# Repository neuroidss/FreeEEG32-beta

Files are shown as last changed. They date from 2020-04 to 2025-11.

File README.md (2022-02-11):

# FreeEEG32-beta

### FreeEEG32 Beta, launching soon on [Crowd Supply](https://www.crowdsupply.com/neuroidss/freeeeg32)!

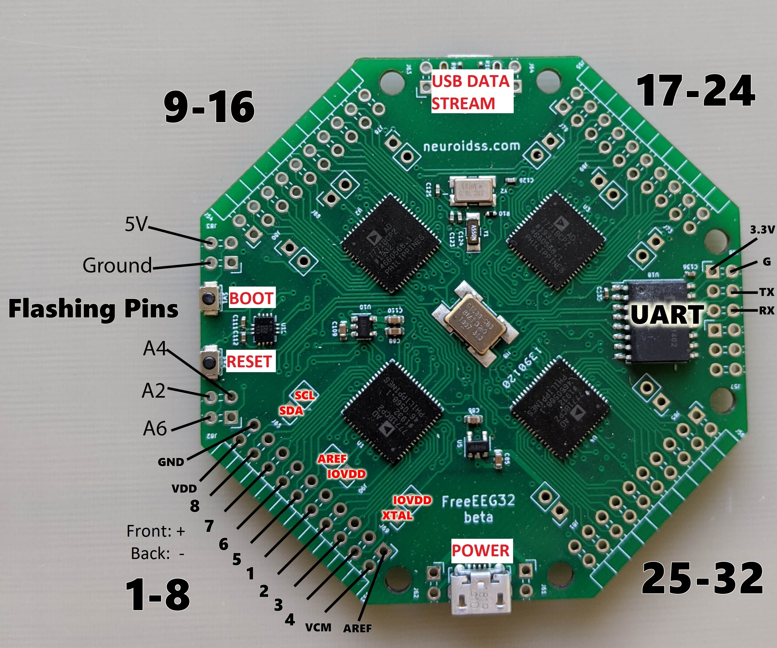
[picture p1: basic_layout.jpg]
basic_layout


### Setup

Docker container setup (Linux). Extract the following and run:
- Compilation: `./gcc-arm-none-eabi_run.sh`
- Flashing: `sudo ./openocd_flash.sh`

[Flashing via AC6 with STM32 Blue Pill](https://github.com/neuroidss/FreeEEG32-beta/blob/master/SetupGuides/FreeEEG32_Flashing_via_AC6_w_STM32F103_BluePill.md)

The AC6 stuff is deprecated but the blue pill is still needed.

[OpenVIBE Setup](https://github.com/neuroidss/FreeEEG32-beta/blob/master/SetupGuides/FreeEEG32_OpenVibe_Docker_Readme.md)

### Production files
Gerber:   https://github.com/neuroidss/FreeEEG32-beta/blob/master/AssemblyFiles/KiCAD/out/gerber.zip

Assembly: https://github.com/neuroidss/FreeEEG32-beta/blob/master/AssemblyFiles/KiCAD/out/assembly.zip

BOM:      https://github.com/neuroidss/FreeEEG32-beta/blob/master/AssemblyFiles/bom/components%20FreeEEG32%20beta.csv

PCB fabrication constraints:
* Dims: 70mm x 70mm
* Layers: 4
* Thickness: 1.6mm (can vary, thicker = sturdier)
* Surface finish: HASL Lead free or ENIG (more expensive)
* Material: FR4

Assembly constraints:
* Unique parts: 33 (27 without pin headers)
* SMT Pads:  169
* Thruhole: 23 (pin headers only)
* Assembly sides: both

This project is being launched with the help of [HEG Alpha](hegalpha.com) to make science more accessible.
Custom 2 channel and 19 channel headsets are available by Bernard Markus.

### More

Neuroidss home: https://neuroidss.com

[Alpha 1.5 repo with more content and tests](https://github.com/neuroidss/FreeEEG32-alpha1.5)

[BrainFlow support](https://brainflow.readthedocs.io/en/stable/)

[Webapp (WIP)](https://github.com/moothyknight/eegpwa)

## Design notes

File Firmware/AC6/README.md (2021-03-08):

Use these files in AC6 or with OpenOCD to update the hardware.

Recent Updates
- Windows compatibility
- 80Mhz downclock for power saving / heat

Notes:
Output is functionally only 256Hz for some reason and printing duplicates at 512Hz.

Search "dec" in Src/main.c to tweak decimation rate settings which will change it, we are working on finding the best fix.

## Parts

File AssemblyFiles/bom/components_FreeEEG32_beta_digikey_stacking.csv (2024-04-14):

Designator | Manufacturer Part Number or Seeed SKU | Qty | Link | Description | alt
U1,U2,U4,U3 | AD7771BCPZ | 4 | https://www.digikey.it/en/products/detail/analog-devices-inc/AD7771BCPZ/7649198 | IC ADC 24BIT SIGMA-DELTA 64LFCSP
U7 | ADR4525BRZ | 1 | https://www.digikey.it/en/products/detail/analog-devices-inc/ADR4525BRZ/3196871 | IC VREF SERIES 2.5V 8SOIC
U18 | ADUM1402BRWZ | 1 | https://www.digikey.it/en/products/detail/analog-devices-inc/ADUM1402BRWZ/655701 | digital isolator 10Mbps 2.7÷5.5VDC SMD SO16-W | ADUM142E1BRWZ
U17 | ADUM3160BRWZ | 1 | https://www.digikey.it/en/products/detail/analog-devices-inc/ADUM3160BRWZ/2361054 | Digital Isolator CMOS 2-CH 12Mbps 16-Pin SOIC W Tube
U8 | CB3LV-3I-8M1920 | 1 | https://www.digikey.it/en/products/detail/cts-frequency-controls/CB3LV-3I-8M192000/663652 | XTAL OSC XO 8.1920MHZ HCMOS TTL
Y1 | FC-135 32.7680KA-A5 | 1 | https://www.digikey.it/en/products/detail/epson/FC-135-32-7680KA-A5/5259895 | CRYSTAL 32.7680 KHZ 12.5PF SMD
J53,J56,J55,J54 | 68021-220HLF | 4 | https://www.digikey.it/en/products/detail/amphenol-cs-fci/68021-220HLF/1878576 | CONN HEADER R/A 20POS 2.54MM
C122 | C0603C475K9PACTU | 1 | https://www.digikey.it/en/products/detail/kemet/C0603C475K9PAC7867/754744 | CAP CER 4.7UF 6.3V 10% X5R 0603
J37,J51 | 105017-1001 | 2 | https://www.digikey.it/en/products/detail/molex/1050171001/5293188 | CONN RCPT USB2.0 MICRO B SMD R/A
U13 | 47352-1001 | 1 | https://www.digikey.it/en/products/detail/molex/0473521001/2404949 | CONN MICRO SD CARD PUSH-PUSH R/A
C125,C123,C126,C124 | GRM1555C1H200JA01D | 4 | https://www.digikey.it/en/products/detail/murata-electronics/GRM1555C1H200JA01D/3693839 | CAP CER 20PF 50V C0G/NP0 0402
C113,C92,C115 | GRM188R60J106ME47D | 3 | https://www.digikey.it/en/products/detail/murata-electronics/GRM188R60J106ME47D/965910 | CAP CER 10UF 6.3V 20% X5R 0603
C85,C110,C104,C100,C88,C87,C86,C109 | GRM188R71A225KE15D | 8 | https://www.digikey.it/en/products/detail/murata-electronics/GRM188R71A225KE15D/1033256 | CAP CER 2.2UF 10V 10% X7R 0603
C90 | GRM21BR60J226ME39L | 1 | https://www.digikey.it/en/products/detail/murata-electronics/GRM21BR60J226ME39L/586711 | Multilayer Ceramic Capacitors MLCC Surface Mount 0805 22uF 6.3 Volts X5R 20%
SW1,SW2 | B3U-1000P | 2 | https://www.digikey.it/en/products/detail/omron-electronics-inc-emc-div/B3U-1000P/1534338 | Switch Tactile N.O. SPST Round Button Gull Wing 0.05A 12VDC 1.5N SMD Embossed T/R
D1,D2 | MBR0520LT1G | 2 | https://www.digikey.it/en/products/detail/onsemi/MBR0520LT1G/918574 | Rectifier, Schottky Power; Plastic Sod-123; 0.5 a @ +90c If; +125; 20v; 1000
C81,C10,C12,C127,C128,C129,C130,C16,C18,C2,C21,C23,C25,C27,C29,C31,C33,C37,C39,C4,C42,C46,C48,C50,C52,C54,C58,C6,C60,C63,C65,C67,C69,C71,C73,C75,C79,C8,C84,C44 | CL05A105KO5NNNC | 40 | https://www.digikey.it/en/products/detail/samsung-electro-mechanics/CL05A105KO5NNNC/3886725 | CAP CER 1UF 16V X5R 0402
C98,C1,C101,C102,C103,C105,C106,C107,C108,C11,C111,C112,C114,C13,C131,C132,C133,C134,C135,C136,C137,C138,C14,C15,C17,C19,C20,C22,C24,C26,C28,C3,C30,C32,C34,C35,C36,C38,C40,C41,C45,C47,C49,C5,C51,C53,C55,C56,C57,C59,C61,C62,C64,C66,C68,C7,C70,C72,C74,C76,C77,C78,C80,C82,C83,C9,C91,C93,C94,C95,C96,C97,C99,C43,C89,C139 | CL05B104KO5NNNC | 76 | https://www.digikey.it/en/products/detail/samsung-electro-mechanics/CL05B104KO5NNNC/3886659 | CAP CER 0.1UF 16V X7R 0402
J85,J88,J89,J90,J79,J81,J78 | SSQ-102-03-G-S | 7 | https://www.digikey.it/en/products/detail/samtec-inc/SSQ-102-03-G-S/1111559 | CONN RCPT 2POS 0.1 TIN PCB | SSQ-102-03-G-S | ED4264-02-ND | SSA-102-W-T | ED5764-02-ND | SSQ-102-03-T-S | 316-43-102-41-003000 | 316-93-102-41-008000 | SS-102-TT-2 | 310-87-102-41-001101 | 801-87-002-10-001101 | 311-43-102-41-001000
J65,J80,J73,J69 | PRPC001DAAN-RC | 4 | https://www.digikey.it/en/products/detail/sullins-connector-solutions/PRPC001DAAN-RC/2775293 | CONN HEADER VERT 2POS | PRPC001DAAN-RC | TSW-101-07-F-D | A26564-ND | GEC01DAAN
U11 | LSM6DSOXTR | 1 | https://www.digikey.it/en/products/detail/stmicroelectronics/LSM6DSOXTR/9841882 | IMU ACCEL/GYRO I2C/SPI 14TFLGA | LSM6DS3TR | LSM6DSRXTR | LSM6DSOXTR
U9 | STM32H743ZIT6U | 1 | https://www.digikey.it/en/products/detail/stmicroelectronics/STM32H743ZIT6U/10326788 | HIGH-PERFORMANCE AND DSP WITH DP
J62,J63,J64,J61 | 68021-402HLF | 4 | https://www.digikey.it/en/products/detail/amphenol-cs-fci/68021-402HLF/4273761 | CONN HEADER R/A 2POS | PREC001DBAN-M71RC | TSW-101-08-T-D-RA | PEC01DBAN | 9-103795-0-01 | 68021-402HLF | HTSW-101-08-T-D-RA
J83,J82 | 68021-404HLF | 2 | https://www.digikey.it/en/products/detail/amphenol-cs-fci/68021-404HLF/1878465 | CONN HEADER R/A 4POS 2.54MM | PREC002DBAN-M71RC | M20-9950245 | TSW-102-08-T-D-RA | HTSW-102-08-T-D-RA | 68021-404HLF
J57,J58 | 68021-406HLF | 2 | https://www.digikey.it/en/products/detail/amphenol-cs-fci/68021-406HLF/1878488 | CONN HEADER R/A 6POS 2.54MM | PREC003DBAN-M71RC | PH2RA-06-UA | TSW-103-08-T-D-RA |  | 68021-406HLF
U19 | ISO7341CDW | 1 | https://www.digikey.it/en/products/detail/texas-instruments/ISO7341CDW/5125383 | DGTL ISO 3KV 4CH GEN PURP 16SOIC | ADUM141E1BRWZ
U5,U6,U10 | LP5907QMFX-3.3Q1 | 3 | https://www.digikey.it/en/products/detail/texas-instruments/LP5907QMFX-3-3Q1/5013206 | IC REG LINEAR 3.3V 250MA SOT23-5 | ADP7118AUJZ-3.3-R7
U12 | SN6505BDBVR | 1 | https://www.digikey.it/en/products/detail/texas-instruments/SN6505BDBVR/5994596 | IC TRANSFORMER DRIVER 6SOT-23
Y2 | 7B-16.000MEEQ-T | 1 | https://www.digikey.it/en/products/detail/txc-corporation/7B-16-000MEEQ-T/2207718 | CRYSTAL 16.0000MHZ 10PF SMD
T1 | 750315371 | 1 | https://www.digikey.it/en/products/detail/w%C3%BCrth-elektronik/750315371/5799562 | XFRMR FWD P-P DC/DC CONV SMD
R102,R100,R101,R99 | RC0402FR-0724RL | 4 | https://www.digikey.it/en/products/detail/yageo/RC0402FR-0724RL/5280933 | RES SMD 24 OHM 1% 1/16W 0402
R10 | RC0402JR-070RL | 1 | https://www.digikey.it/en/products/detail/yageo/RC0402JR-070RL/726406 | RES 0.0 OHM 1/16W JUMP 0402 SMD
R114,R116,R117,R115 | DNP | 4 | https://www.digikey.it/en/products/detail/yageo/RC0402JR-070RL/726406 | RES 0.0 OHM 1/16W JUMP 0402 SMD | RC0402JR-070RL
R109,R108 | RC0402JR-074K7L | 2 | https://www.digikey.it/en/products/detail/yageo/RC0402JR-074K7L/726477 | RES 4.7K OHM 1/16W 5% 0402 SMD

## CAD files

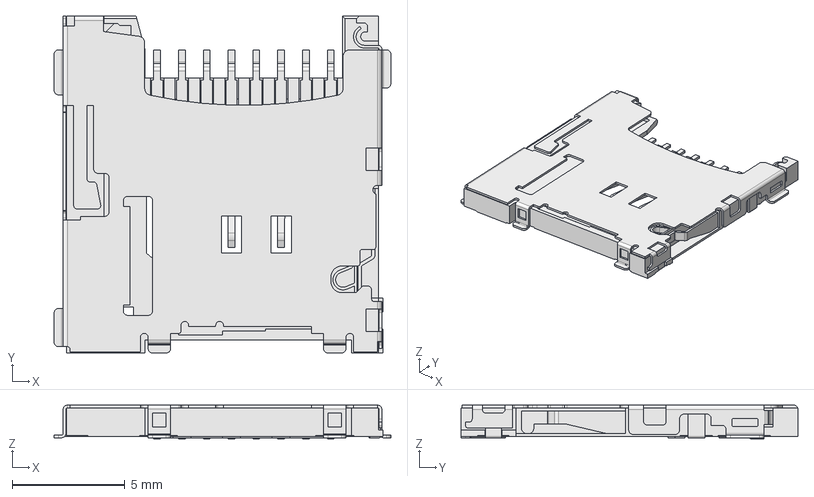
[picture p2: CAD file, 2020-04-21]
AssemblyFiles/KiCAD/3d/Connectors/5031821852.step
14.9 x 14.9 x 1.50 mm

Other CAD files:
AssemblyFiles/KiCAD/3d/Connectors/5031821852.stp

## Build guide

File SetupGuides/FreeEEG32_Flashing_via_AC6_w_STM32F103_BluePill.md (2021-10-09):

# FreeEEG32 Flashing via AC6 w/ STM32F103 Blue Pill

#### Materials

[STM32F103C8T6 "Blue Pill"](https://stm32-base.org/boards/STM32F103C8T6-Blue-Pill.html)
Make sure it's genuine!

FreeEEG32 board.

2x MicroUSB cords

#### Software:

##### FreeEEG32 software
[System Workbench for STM32](https://www.openstm32.org/System%2BWorkbench%2Bfor%2BSTM32) (registration required, recommend you use this on Ubuntu 16.04 or 18.04 as this is how we will access OpenVibe)

FreeEEG32 Firmware (included in this repo under /Firmware/AC6). Replace the firmware files with the contents of [EEG_WindowsCompat.tar.gz](https://github.com/neuroidss/FreeEEG32-beta/blob/master/Firmware/AC6/EEG_WindowsCompat.tar.gz) to enable Windows (and probably Mac) compatibility, this will get integrated once tested fully. 

## Setting up the Blue Pill

## New Method

You need an STLink V2 USB, these normally come in packs with Blue Pills

STM32CubeProgrammer: https://www.st.com/en/development-tools/stm32cubeprog.html

Plug the SWDIO, SWDCLK, and 3v3 + GND pins on the end of the Blue Pill to the correct pins on the STLink. Place the Blue Pill in Programming mode by placing the jumper pin OPPOSITE of the reset button to Position 1.



Connect to the STLink (plugged into a USB2.0 port, 3.0 wouldn't connect for me) via the Programmer software above. Open the CMSIS-DAP V1 F103 Firmware (included in this repo under /Firmware/CMSIS-DAP_hex)
with the program, click the tab, and then click the Download option and it should update the Blue Pill. 

Capture

You should see the blue pill go from flashing to not flashing anymore on one of the LED while the power LED should remain lit. This means it worked. 

Unplug the Blue Pill and STLink, place the Blue Pill back in boot mode (jumper back to Position 0) and plug the MicroUSB cable in, and it should now be recognized as CMSIS-DAP by your computer.

### Old method (doesn't work anymore last we checked)

##### Blue Pill software

FT232RL USB to UART converter OR ESP32 developer board with EN pin shorted to ground.

[STM32 Flasher Demonstrator GUI](https://www.st.com/en/development-tools/flasher-stm32.html)

CMSIS-DAP V1 F103 Firmware (included in this repo under /Firmware/CMSIS-DAP_hex)

This part adapted from [Circuit Digest](https://circuitdigest.com/microcontroller-projects/programming-stm32f103c8-board-using-usb-port)

With the STM32 Flasher Demonstrator GUI installed and the CMSIS-DAP firmware downloaded, wire up your Blue Pill to your USB-UART converter 
(you can’t use the Micro-USB port by default) like so:

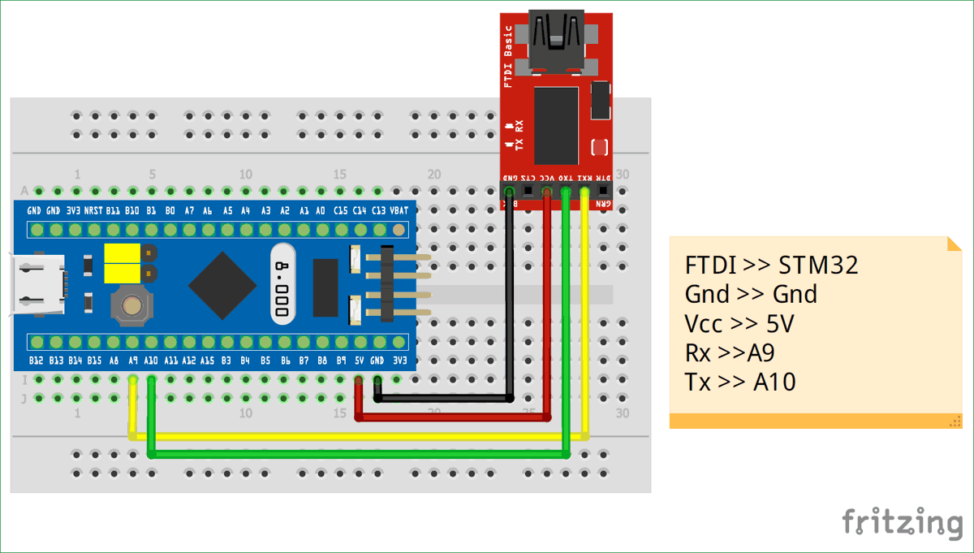
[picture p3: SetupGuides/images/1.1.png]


Place the Blue Pill in programming mode by placing the TOP yellow jumper pin in this image to the “1” position.

*If using an ESP32 dev board instead of an FT232RL, short the EN to GND first to disable the ESP32 chip and use only the USB-UART chip on-board.*

Plug the USB-UART converter into the computer after it’s wired up and then open the Flasher Demonstrator GUI. Select the correct COM port 
for the USB-UART converter and hit next.

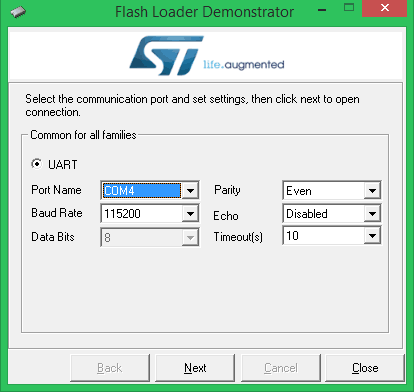
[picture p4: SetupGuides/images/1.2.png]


Click next, see that the Blue Pill has been found (adjust the wires and reopen the GUI to try again if it doesn’t work the first time), 
and then select your Blue Pill’s memory size (64K is the most common, the previous window tells you the memory size). 

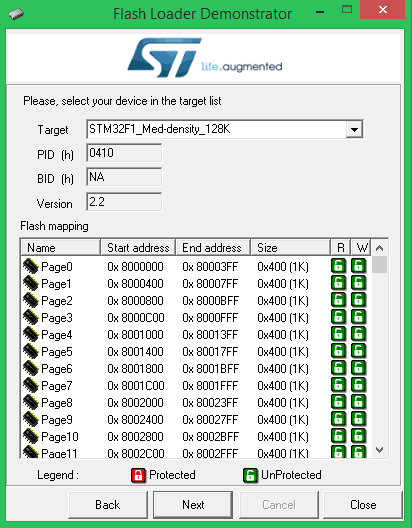
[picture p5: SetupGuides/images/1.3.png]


In the next window select “Download to device,” navigate to the CMSIS-DAP_hex folder in the Firmware folder of this repo and select "CMSIS-DAP-V1-F103.hex" and click Next

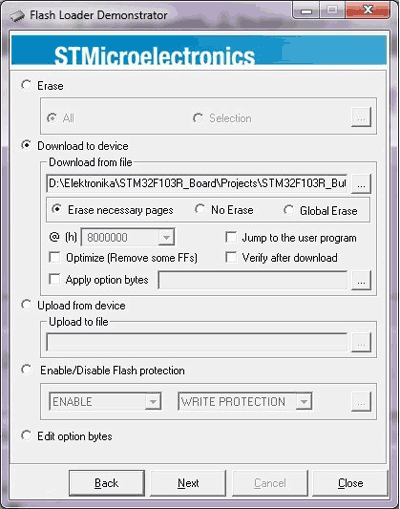
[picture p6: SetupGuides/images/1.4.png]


You should see it downloading to the device, the progress bar turns green on success. You are finished setting up your Blue Pill! Place it back into Operating mode by switching the jumper back to the 0 position.

Check if it worked by removing the USB-UART converter and plugging into the MicroUSB port on the Blue Pill. You should see the CMSIS-DAP be recognized on the Windows computer.

## Flashing the FreeEEG32

First, in /Firmware/AC6 unzip the STM32H743ZI_alpha1.5_SD_CDC.zip/.tar.xz
to the same folder.

With AC6 installed, click on the .cproject file in the newly unzipped folder 
to open it. You may not find AC6 at first, go to its install location, open the terminal and enter ./eclipse then pin the app once it starts.

First select Project > Build All to build the firmware.

Now we need to set up the debug configuration real quick. 

You need to copy a file first.

In AC6/SystemWorkbench/plugins, search for cmsis-dap.cfg and copy the one found in com.st.stm32ide.debug/resources/openocd/st_scripts/interface to the same subfolder in fr.ac6.mcu.debug to make the CMSIS-DAP be recognized properly.

If your DAP is not connecting you may also need to add this rule:
```
# mbed CMSIS-DAP
ATTRS{idVendor}=="0d28", ATTRS{idProduct}=="0204", MODE="664", GROUP="plugdev"
KERNEL=="hidraw*", ATTRS{idVendor}=="0d28", ATTRS{idProduct}=="0204", MODE="664", GROUP="plugdev"
```

via

```
cd /etc/udev/rules.d
sudo touch newrule.rules
sudo gedit newrule.rules
```

then paste the above rule, save, and use the command

`sudo udevadm control --reload-rules`

In the tool bar click Run > Debug Configurations

Select Ac6 STM32 Debugging then click the New icon in the top left corner. Name this CMSIS-DAP or something.

In the Main tab, select Browse under Project: and select the current project, then in the C/C++ Application section select Search Project and it should fill out with the .elf file automatically.

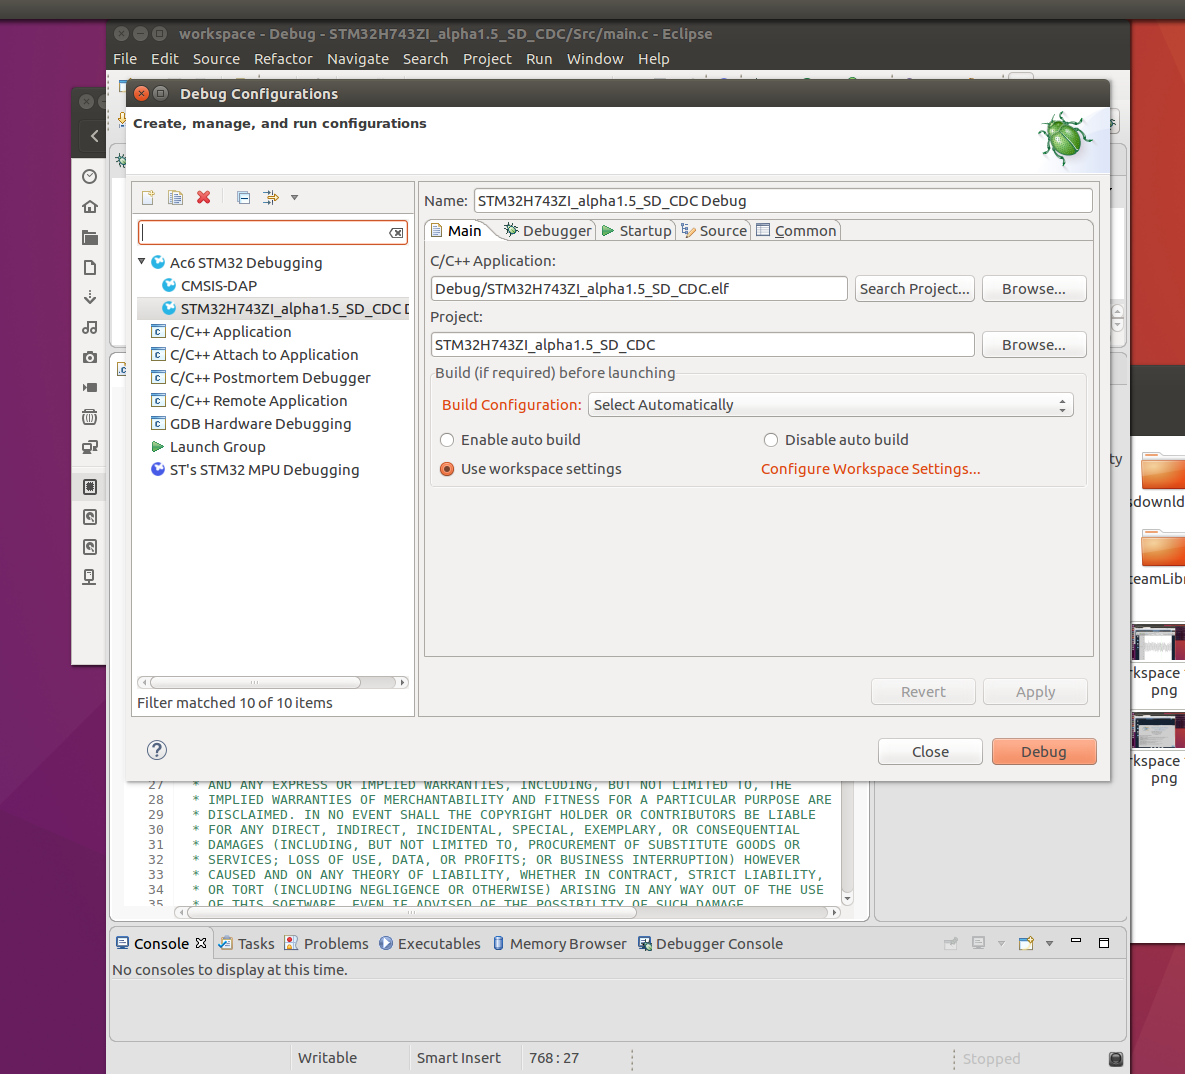
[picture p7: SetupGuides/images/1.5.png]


In the Debugger tab, select User Defined under Configuration Script and find "STM32H743ZI_alpha1.5.cfg" under the current project folder.

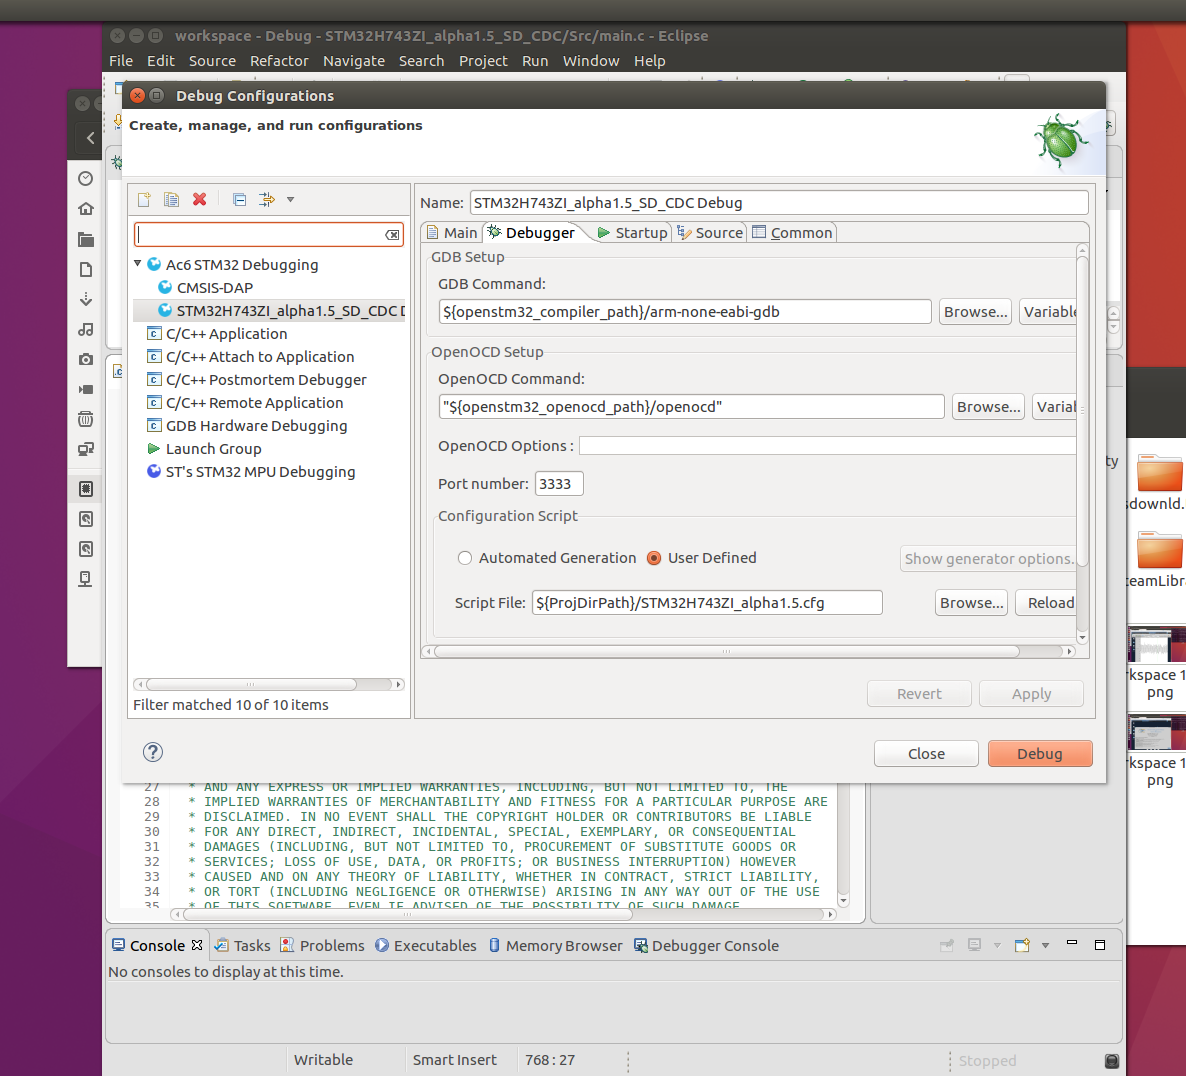
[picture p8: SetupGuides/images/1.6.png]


With that set, now let's wire up the Blue Pill to the FreeEEG32. Connect the Blue Pill to the pins near the buttons like so:



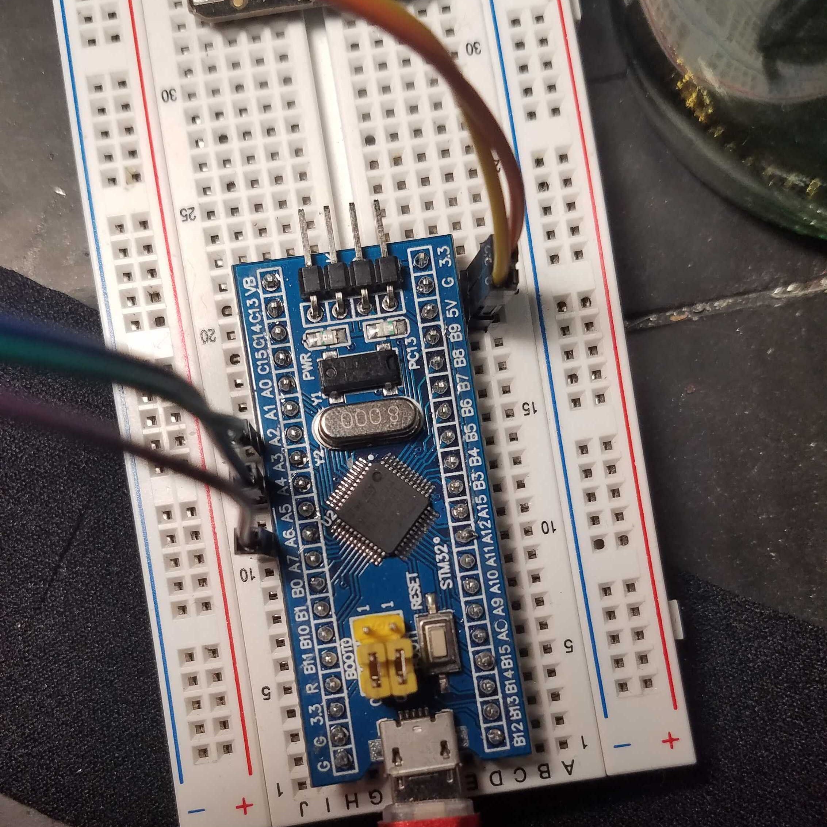
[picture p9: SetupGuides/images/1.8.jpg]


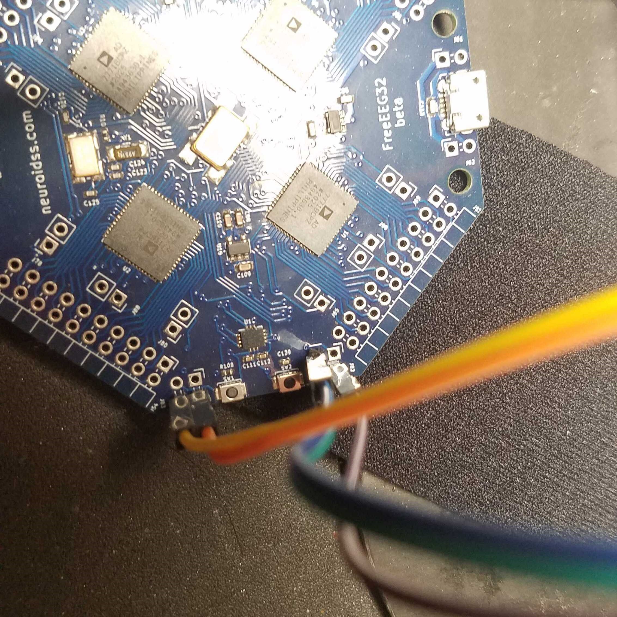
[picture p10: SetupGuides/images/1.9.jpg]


Now plug in the CMSIS-DAP via MicroUSB as well as the FreeEEG32's power USB slot.

Now, holding down the boot button firmly, click Run (the green Play button) to upload the firmware. This may take a few tries.

If it's working you'll see it say "Programming started" and hang for a bit,
then you should see it eventually scroll a bunch then you'll see a message "Verified OK" meaning it's done.

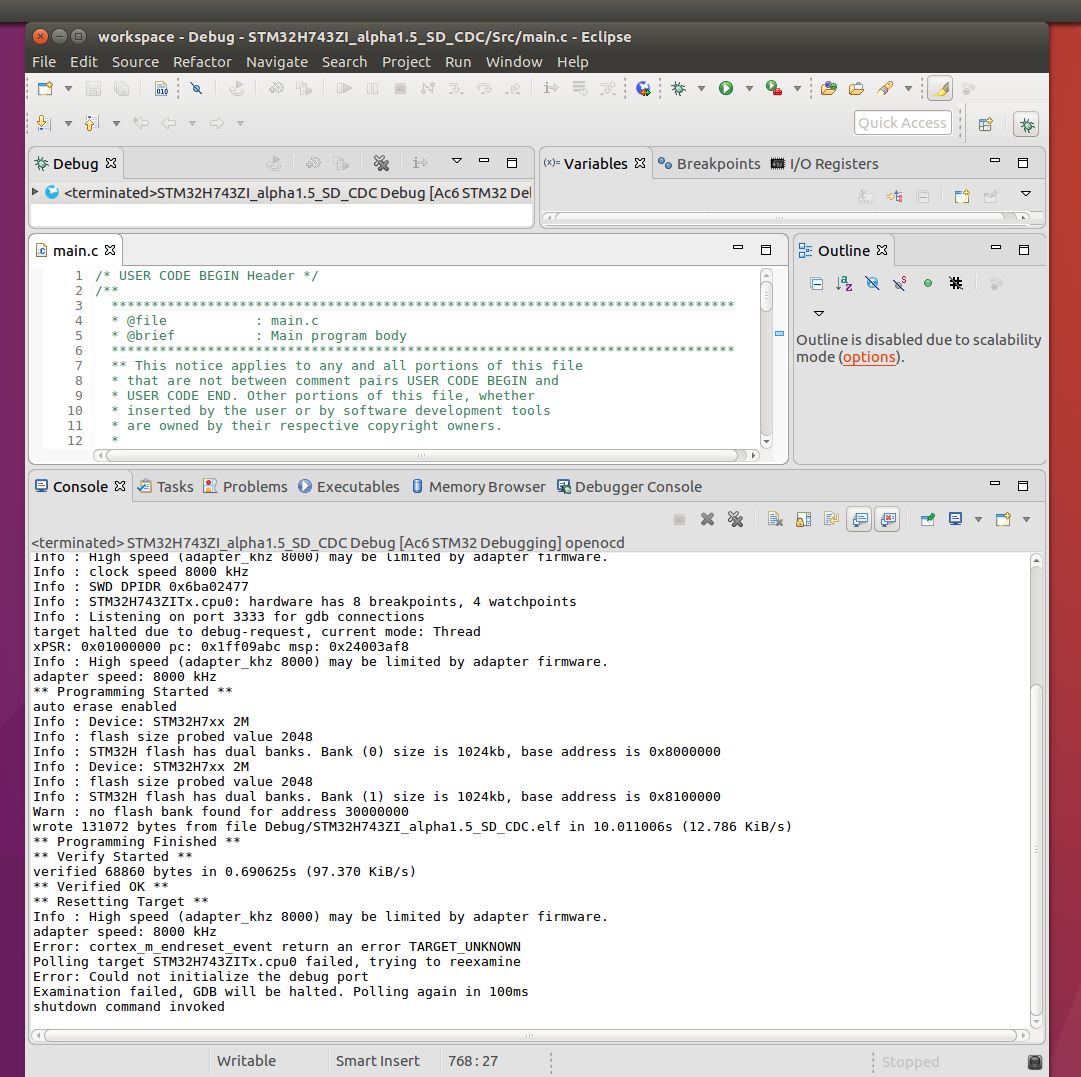
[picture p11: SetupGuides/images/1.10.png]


## Testing the Firmware

To test if it worked, first unplug everything then remove the Blue Pill. Then plug the EEG in via both USB ports. It should start to warm up.

Assuming you are on Ubuntu now, open a terminal and type in "lsusb", you should see an ST Microelectronics STM32F407 board recognized. That's the EEG!

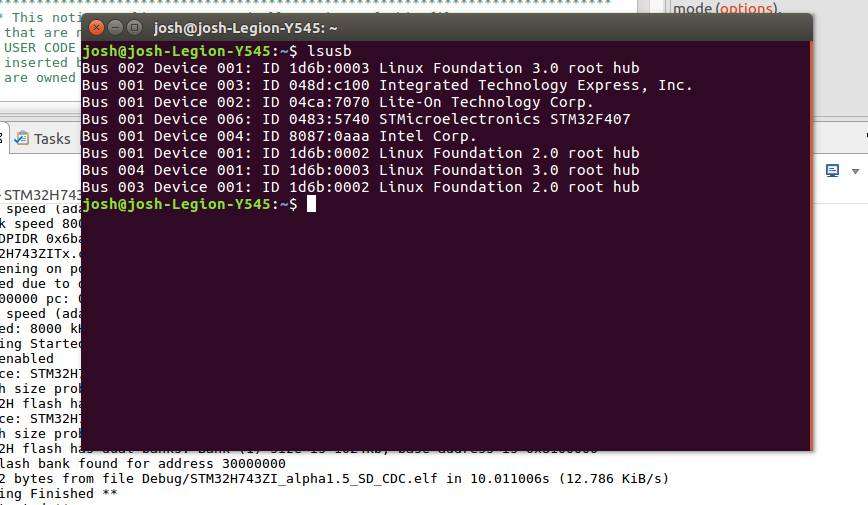
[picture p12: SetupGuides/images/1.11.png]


To read the output you must use something like putty, with baud rate 921600 (115200 with the Windows fix). On Ubuntu the device will be at /dev/ttyACM0 when plugged via MicroUSB.

Alternatively, you can test the output using a USB-UART converter on the UART pins (see diagram above), wired up like so:

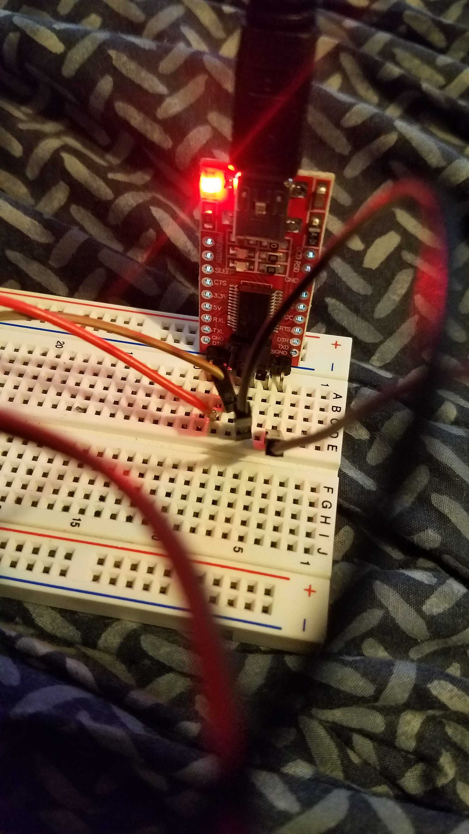
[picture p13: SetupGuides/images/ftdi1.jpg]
ftdi1

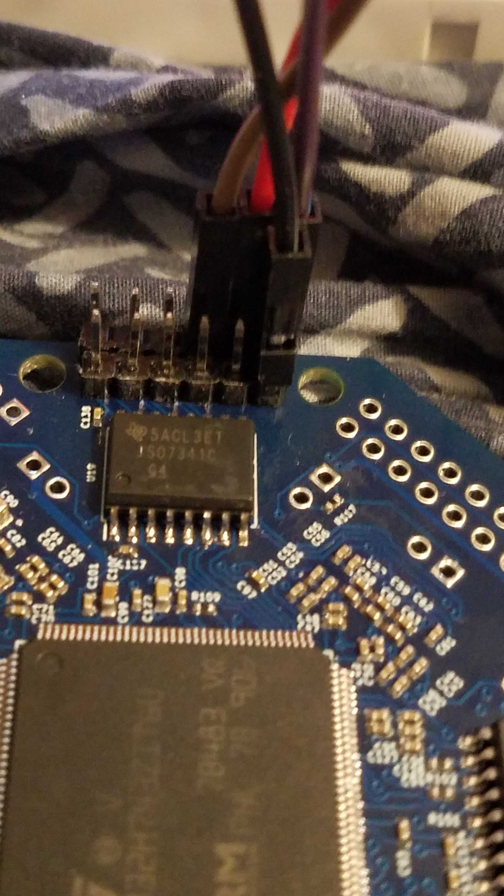
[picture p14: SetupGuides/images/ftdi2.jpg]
ftdi2


This concludes this guide. Now we can move on to testing the signal output with OpenVibe!

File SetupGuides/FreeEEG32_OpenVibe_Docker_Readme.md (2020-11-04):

# FreeEEG32 OpenVibe Docker Readme

#### Materials:

FreeEEG32 Board

2x MicroUSB cords

#### Software:

Install on Ubuntu (16.04 or 18.04 preferred)

[Docker](https://docs.docker.com/get-docker/)

[Docker Compose](https://docs.docker.com/compose/install/)

## First test the data stream

Assuming you are using Ubuntu: 

Connect both USB wires to your FreeEEG32.

Open the command prompt and type "lsusb" to see the device connected. You should see an ST Microelectronics device listed.

Navigate to your /dev/ folder and look for a file that should say: tty_ACM0. This should disappear when you unplug the FreeEEG32.

Open a software like PuTTY or KiTTY that can test serial streams. Enter /dev/tty_ACM0 into the hostname and set the speed (baudrate) to 921600.

You should see a big stream of gibberish, which is encoded data. This can be switched in the firmware to a number stream. This means it should work just fine in OpenVIBE.

## Setting up OpenVIBE with Docker Compose

With Docker and Docker Compose installed for Ubuntu, in the OpenVIBE folder from this repo, first extract openvibe-freeeeg32.tar.gz to somewhere (the same folder as the .tar.gz file is fine).

Now open this extracted openvibe-freeeeg32 folder and right click and select Open Terminal.

In the Terminal that opens, use the command "sudo docker-compose up" and it will download a bunch of stuff to create a Docker container with OpenVIBE running.

Once it finishes downloading everything you should see some messages with colored text in brackets. That means the Docker Container is now running. 

Press Ctrl+C twice in the Terminal to close the server. Now plug in your EEG with both wires if it's not already, then re-run "sudo docker-compose up" in the same Terminal.

Now open your browser and enter the address
http://localhost:6904/?password=vncpassword

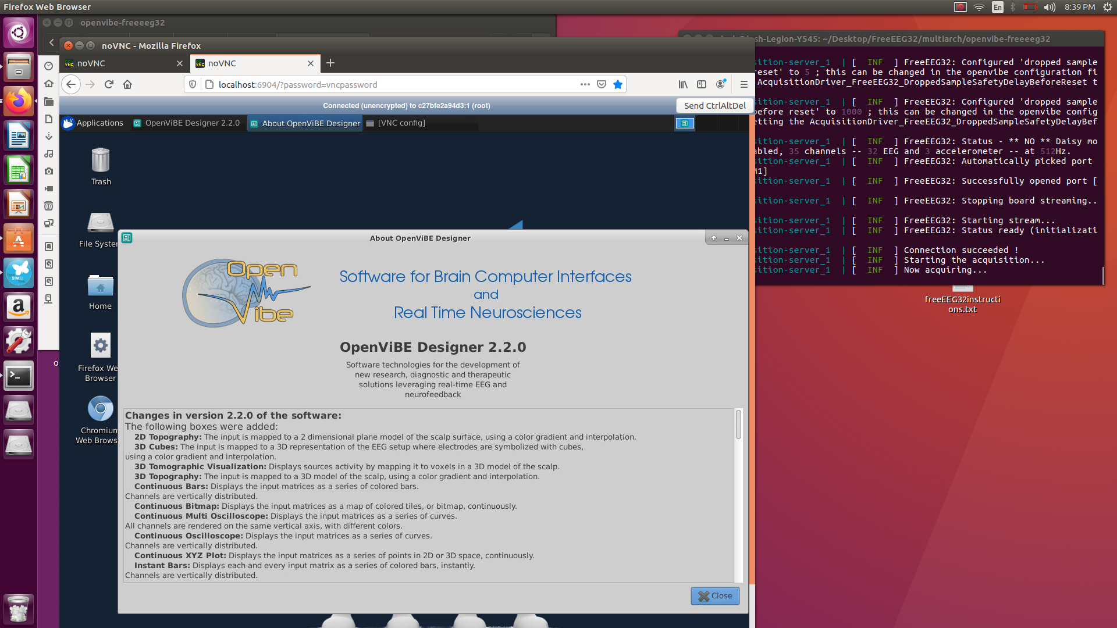
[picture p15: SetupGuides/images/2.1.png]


There is also a server interface at http://localhost:6902/?password=vncpassword where you can manually connect, however it should run automatically on default settings.

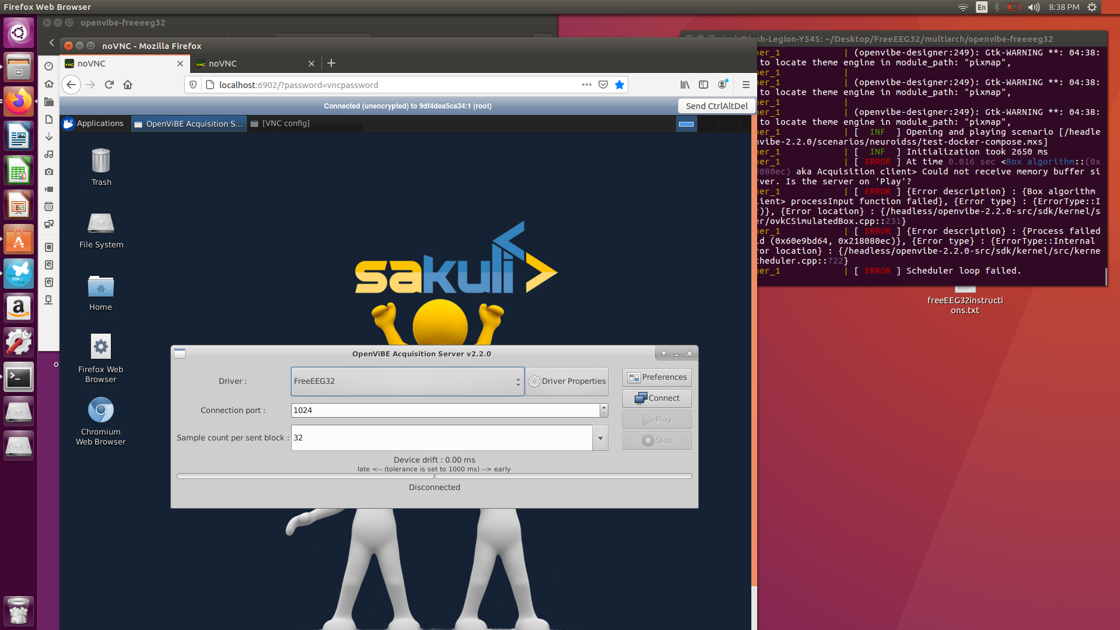
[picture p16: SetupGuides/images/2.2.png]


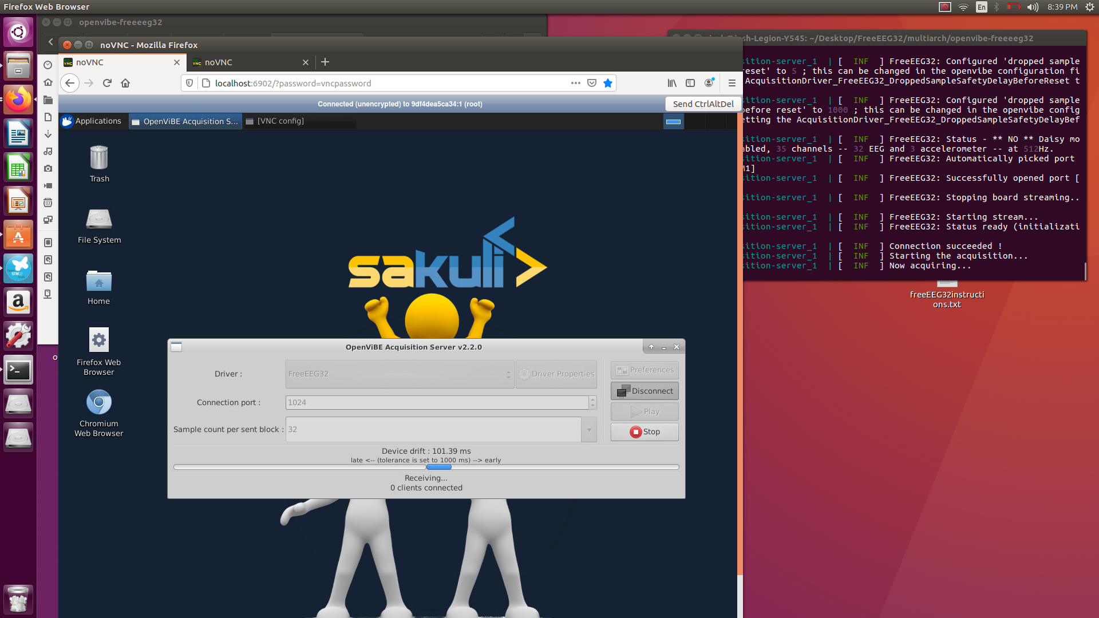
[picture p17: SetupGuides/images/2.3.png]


If the EEG connected successfully, you will see a "Now acquiring..." message in the Terminal and no timeout messages. If you see timeouts, replug the device then rerun the sudo docker-compose up command again.

At http://localhost:6904/?password=vncpassword, you will see the OpenVIBE welcome dialog. Close the welcome dialog to use the Designer GUI.

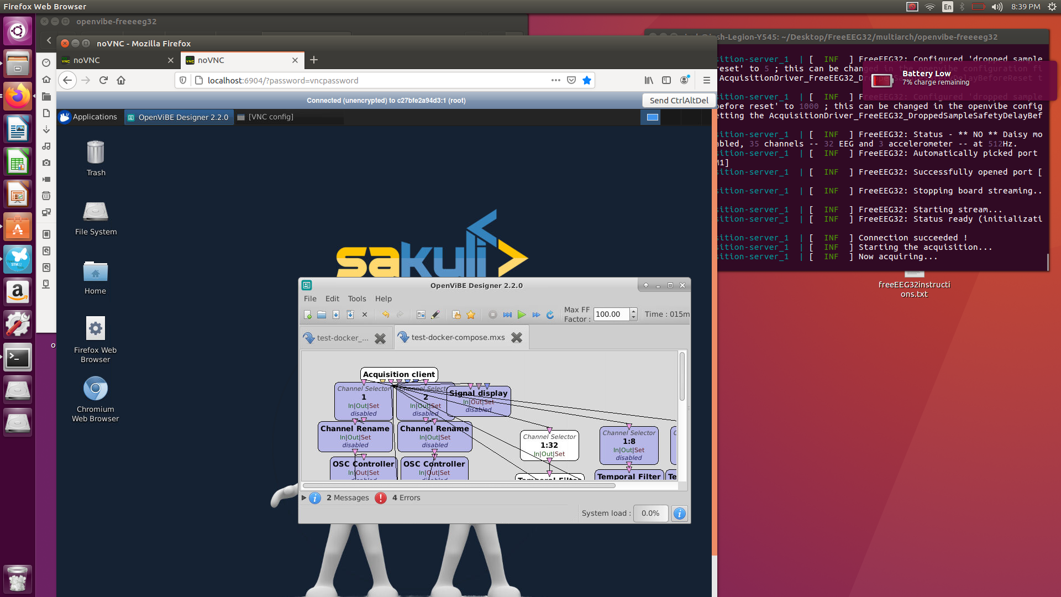
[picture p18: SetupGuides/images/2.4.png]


Click Run in the GUI and you should see a signal chart come up with all of the channels streaming. If any groups of channels aren't streaming while others are that tells you that one of the ADCs had a failure. You can simply tap on any of the signal inputs with your finger to see electrical response.

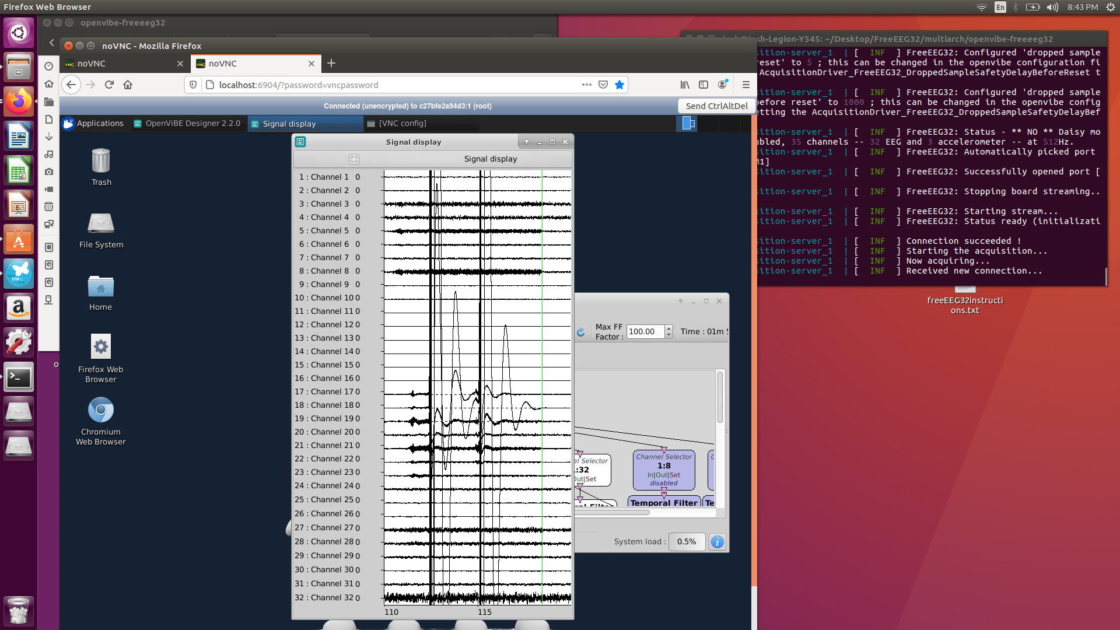
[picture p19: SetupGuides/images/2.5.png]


## Test the signal!

Click the Signal display tab at the top to bring up the menu for the charts. You can select a single channel and shorten the time interval up to see a close up view of signal quality.



Short a + (front) and - (back) analog input together on a single channel and ensure that the noise being measured is less than 0.25uV on average. 
The graph scale is in Microvolts (uV). Select that channel in the signal view and scale it to around 2.00 uV or just select automatic scaling. If it's noisy, ensure that you are not on AC power (i.e. remove your laptop charger if you are on one, desktop may not work depending on location).

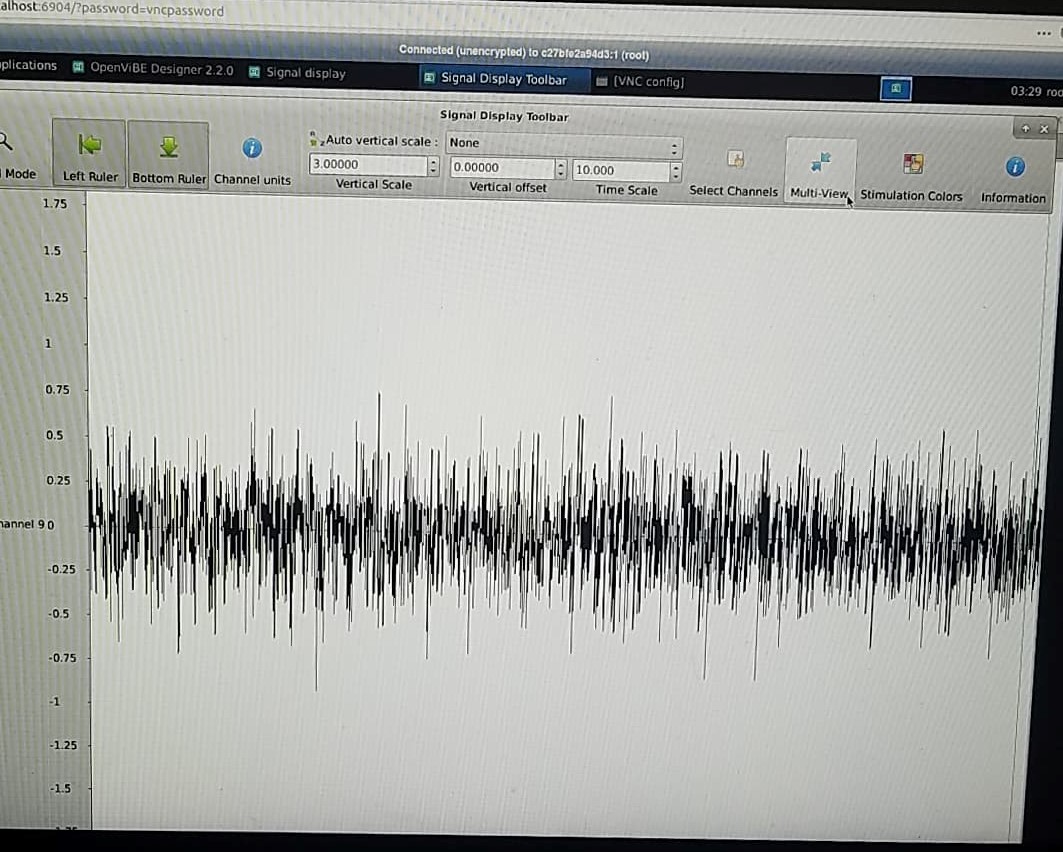
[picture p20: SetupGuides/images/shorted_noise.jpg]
noise


If that looks good enough, now wire up 3 electrodes like so, 2 for a single channel in the + and - slots and 1 in the Gnd position:

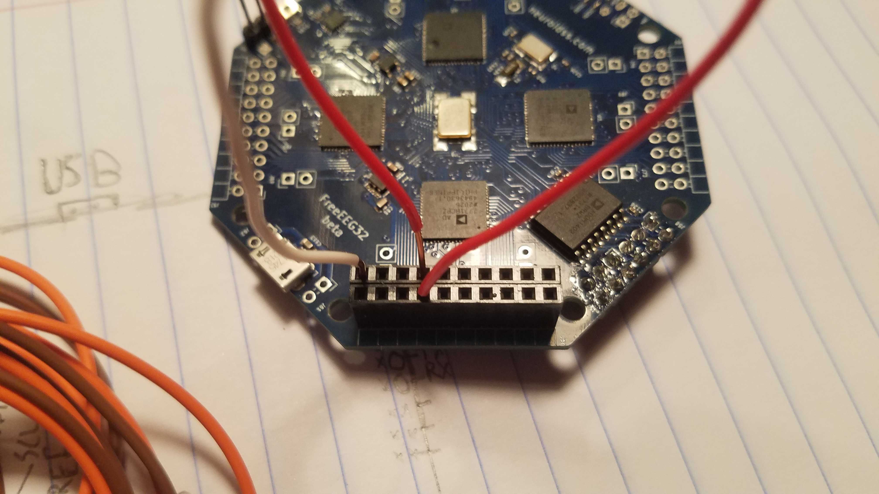
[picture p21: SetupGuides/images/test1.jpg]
test1


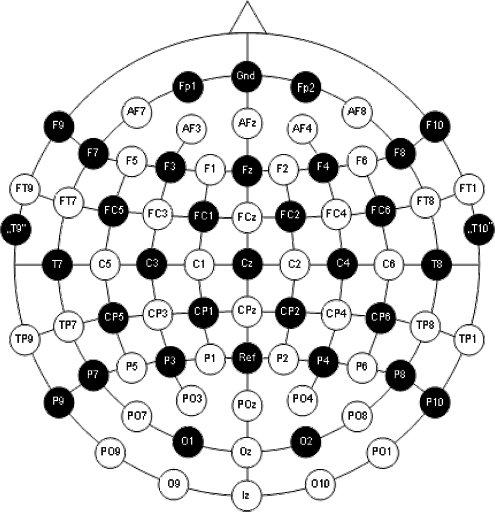
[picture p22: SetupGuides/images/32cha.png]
32cha


For an easy test, put the Gnd electrode on your ear (use tape or something to stick it there if you don't have a clip).
Put the + and - electrode on Fp1 and Fp2. Now wiggle your forehead and move your eyes around, you should see responses with the EEG amplitudes at around 100uV or less. 
The wave forms at small scale should look fairly sine wave-like.

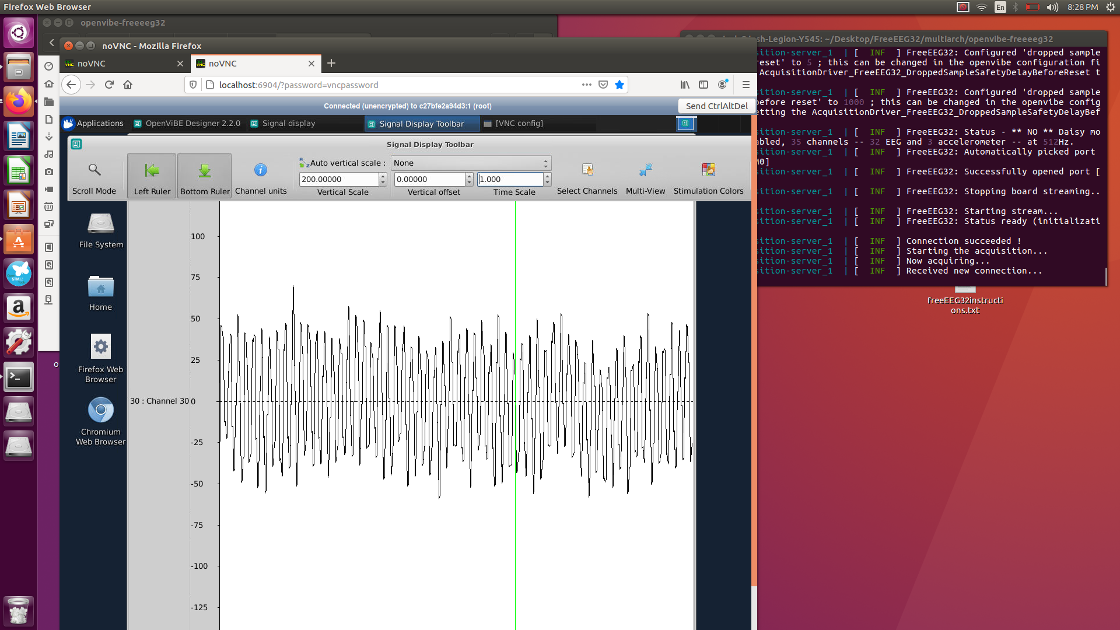
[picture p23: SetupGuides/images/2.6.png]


Another test is to put the + and - leads on O1 and O2 of your visual cortex, then open and close your eyes to see activations.

And that's it really! Good luck!

### Multiple EEGs

You can run multiple EEGs plugged into your computer (you'll need lots of USB ports!) in the same GUI by starting more servers before starting the GUI. Extract [openvibe-freeeeg32-128.zip](https://github.com/neuroidss/FreeEEG32-beta/blob/master/OpenVIBE/openvibe-freeeeg32-128.zip) and try "sudo docker-compose up" in that folder for a 128 channel stack configuration for openvibe, it should work for less than 4 boards too.

That should stream it automatically into OpenVIBE in multiples of 32 channels. Here are 8 plugged into the same PC:

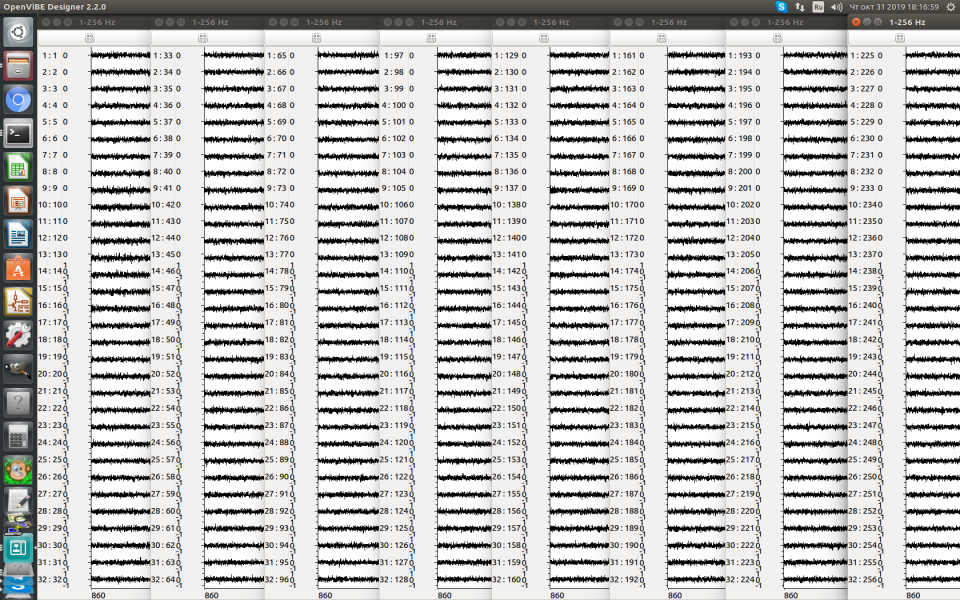
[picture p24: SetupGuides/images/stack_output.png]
stack


For plugin programming, you just need grab multiple virtual serial port streams or create a similar server interface for remote streaming.

### FreeEEG32 OpenVIBE output format

The FreeEEG32 output format mimics OpenBCI's stacked output which is based on Brain Bay's work, while ours is scaled for 32 channels.
You may also change the output to number strings by opening /Inc/main.h in the source code and changing to this on line 286/287 (just comment one out and uncomment the other)
```
#define FREESMARTEEG_OUT FREESMARTEEG_SAI_TEXT_UART7_INT
//#define FREESMARTEEG_OUT FREESMARTEEG_SAI_OPENVIBE_FREEEEG32_CUSTOM_INT
```

In /Src/main.c, search FREESMARTEEG_SAI_OPENVIBE_FREEEEG32_CUSTOM_INT to see how the data is encoded in OpenBCI/BrainBay format.

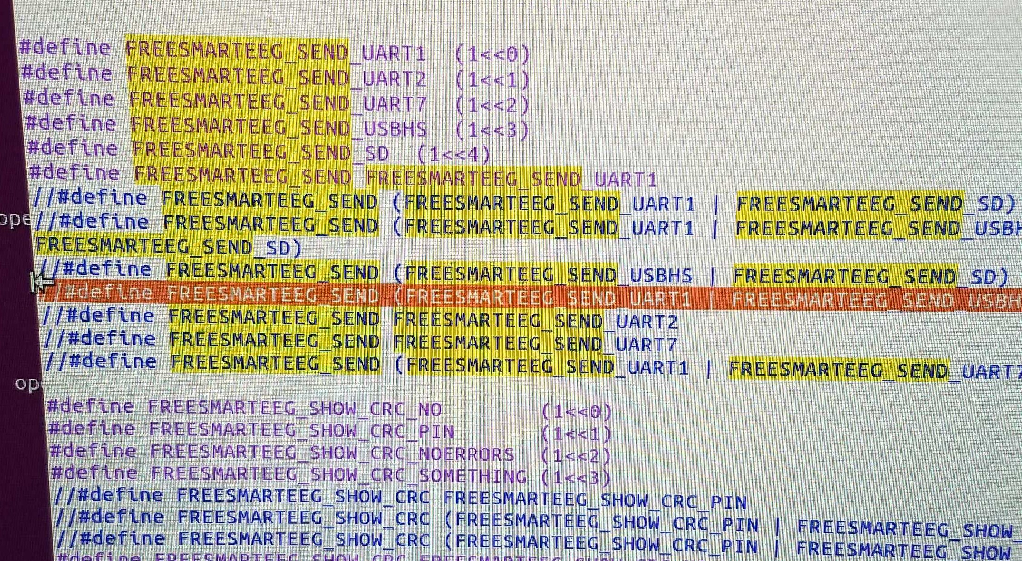
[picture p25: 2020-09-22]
SetupGuides/images/1.12.jpg

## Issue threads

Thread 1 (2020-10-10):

should i go with alpha or beta version + how to stream LIVE EEG data through USB TO UBUNTU RUNNUNG PC

INNFINITEMINDS, 2020-10-10:
Respected SIr,
as i am new to this .please guide ...

as u have provided bom and pcb files ..if i go with and bring all the componenets and print pcb ..assemble it..

than should i able to run and start freeEEg 32 ?

ho can i stream eeg data in an ubuntu pc ? ..if i connect electodes to freeEEG32 device

awaiting for reponse ,
Thanks

arpit

moothyknight, 2020-10-10:
Hey Arpit,

It is not super trivial to have your own boards fabricated and then upload the firmware to the boards once you have them manufactured. The flashing and initial use via Ubuntu instructions are available in this repository. The AD7771s seem to be in short supply as well which adds a lot of wait time, but if you want to go through with it you should supply the BOM, assembly, and gerbers to a site like PCBWay (I recommend) and they can order the parts turnkey for you so you don't have to think about that whole mess.

The beta board is the one we will be launching on Crowd Supply as soon as a partner finishes up his piece.

INNFINITEMINDS, 2020-10-16:
Does this beta board will be open source and how shouldi reproduce it ?
also if iwant to reproduce ..which board should i go?
aplha or beta version ?

awaiting for your reply..
thanks ,
arpit

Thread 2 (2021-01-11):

Join efforts (or at least align them) with HackEEG

dumblob, 2021-01-11:
https://www.crowdsupply.com/starcat/hackeeg

Thoughts?

moothyknight, 2021-01-11:
@dumblob

I'm always down for collaboration but it's not super trivial to get any practical partnerships going other than making some kind of flag to rally around.

For one: we have no pretenses about making big bucks on these devices, the goal is quite the opposite - to tank the cost to buyers without a loss in quality, so profit-first groups (i.e. most groups producing hardware) are immediately scared off from working with us in any form, including OpenBCI whom we already approached (to my surprise, but names don't necessarily mean anything). I'm working on a chip that'll make a 15 dollar 8 channel EEG, there's no money to be made there if you charge an honest margin (i.e. <50% rather than, I dunno, 1000% or whatever the typical margins are).

Secondly: We've got a bunch of our own projects around the whole open source EEG and biofeedback sphere. We're working on more hardware and I'm working on a generic software platform that I'll look to integrate anyone's hardware into after I'm comfortable with the features. So time-wise I don't have much to spare, and I have a few goals for the next few months that at least in my mind are better ideas than anything else happening right now in this space.

I have some serious gripes about the priorities in this industry, and in tech in general. Hardware and to some extent still software design aren't community driven spaces like they should be as a lot of the cost and learning barriers are only recently coming down in a big way. There's so much pretense around it all still which does not help encourage people to get involved or collaborate openly, in fact it ends up wasting more money on poorly informed/disorganized development funded by clueless investors who overestimate the quality of the work they're doing and don't care much about actual ethics (rather, taking advantage of a for-profit health care system). I'm no pro but it doesn't take an expert to see these issues everywhere. I'm all ears for people who actually seriously want to work together, though, but it's not exactly been trivial to come up with something that satisfies everyone due to all this business nonsense and our complete disinterest in exploiting it.

dumblob, 2021-01-11:
I think I share your positions on the state of medical industry (while staying aware that all the first and recurring (re)certifications and approvals from federal organizations & laboratories are super expensive and the money has to come from somewhere for this purpose).

I didn't want to ignite any heated discussion. I just imagined if all these organizations tried to agree on some minimal subset of generic APIs and hardware properties (e.g. which 3 chip architectures to use or how to do low-noise placement & routing of electronic parts on a PCB, etc.), it'd benefit us all. This spec would then evolve over time, but it'd be the first "milestone" for any beginner or integrator (btw. IMHO integration is the future of medical technology - the strong trend of recent years "point of care diagnostics" greatly amplifies that).

So I'm sorry if you have had a rather bad experience with OpenBCI or any other organization. I'm not in contact with any of those, so I didn't know of this. Let's have hope it'll turn out differently after having you as a business partner.

moothyknight, 2021-01-11:
@dumblob The idea of an ideal minimum architecture is pretty much what I'm trying to come up with since that's about all I'm capable of making anyway. This project and Dmitry's continuing work is to try to scale up channel counts on a single board, he's doing 64 channels next.

You can readily look up the latest and greatest chips (which usually happen to be some of the cheapest too) and the datasheets tell you how to get best results on the PCB layouts. The irony is stunningly few people are aggressively hunting the best low cost specs down for beneficial or state of the art tech (optical imaging is the area I'm looking at most right now which is way more underserved than EEG) when this is basically LEGOs now plus a few nuances in PCB design (plus the issue of finding cheap prototype manufacturers like PCBway). You can make a shocking amount of up-to-date hardware before you ever break 30 bucks in parts + assembly costs for TONS of stuff, especially depending on how much you can do yourself.

RE industry costs, sure that's a big issue but so much can be cut back with better project management and ending exploitative relationships (e.g. lab costs, or obtuse shareholders). IMO mass manufacturing of public interest technology should have some kind of public co-operative thing around it driven by universities or some ethical group so it's not just at the mercy of markets and whatever regulations there might or might not be, but that would require a big group of people to have compassion and not be psychotically ignorant if that's even a thing anymore. I don't mean to get heated but I've been completely disappointed by whatever you could call the current leadership around BCI, and it reflects the problems in the wider industry pretty well I think, it's just a joke. There's almost no serious conversation about the kind of wider community we want to foster either even though we are all contributing fragments to a massive evolving base of code and engineering. Personally I think the clock's ticking down on whether we can form proper organizations around all this tech, things are changing really fast and a lot of people could benefit now more than ever with suitably adaptive and compassionate efforts.

For BCI in particular it's potentially transformative for a ton of mental health therapies while completely noninvasive so it's senseless to let it stay exclusive especially if I can succeed even current-day $300+ professional releases for 15 fucking dollars and minimal jank. Think of it like this, we don't even have good clinical validation of any of the things that multi million dollar clinics and tech businesses are placing major cost burden on customers for like with EEG, and if it is valid then why would you want there to be artificial barriers to accessing it whatsoever? I personally don't want people trading a huge portion of their time to me in the form of money for something they think could help liberate them, that seems pretty wrong. That's the general issue with the lack of a public health care system in the US anyway, but one of the barriers to that happening is companies actually getting on board with affordable and humanistic business models, and proper communities forming to echo basic ethics throughout the industry. Well whatever that's all just what sounds good in my echo chamber here, it might not completely reflect reality. I think it's still important to articulate these ideas.

dumblob, 2021-01-11:
I think it's clear where we are now with "medical industry". Thanks for your insights.

Lets leave this open if you don't mind. Just to allow others to help on this front a bit or at least sheir their ideas how to do that.

moothyknight, 2021-01-11:
I will have much to share in the coming months as well

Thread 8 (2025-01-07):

Orientation of y2?

Relys, 2025-01-07:
Hey, so I'm building a FreeEEG32 and I'm having to use this as a replacement since the original part was out of stock: https://www.digikey.com/en/products/detail/txc-corporation/7M-16-000MEEQ-T/2207739

Looking at this photo it appears that the original component has the little solid dot (signifying pin 1) in the upper right corner:

https://github.com/neuroidss/FreeEEG32-beta/blob/master/basic_layout.jpg

However, according to the schematic, isn't this flipped the wrong way? (i.e. should be in lower left corner).

Relys, 2025-01-07:
Ahhh, I see only pins 1 and 2 are used, and according to the datasheet it looks like it can be flipped either way.

Pyrogenez, 2025-03-11:
@Relys - did you get your project up and running?

torinfin, 2025-04-14:
Are there cases/boxes that have been designed to hold these boards 1 or more linked?
I see the one company that was used to make and stuff boards. Have others been used?  I couldn't find a list of vendors people have implemented.

. Thank you.
Torin

On Mar 11, 2025, at 1:55 AM, Pyrogenez ***@***.***> wrote:

@Relys<https://github.com/Relys> - did you get your project up and running?

—
Reply to this email directly, view it on GitHub<https://github.com/neuroidss/FreeEEG32-beta/issues/8#issuecomment-2712749754>, or unsubscribe<https://github.com/notifications/unsubscribe-auth/AS4QDH235TPE33VO6KQMLVD2T2CE7AVCNFSM6AAAAABUYP7OKSVHI2DSMVQWIX3LMV43OSLTON2WKQ3PNVWWK3TUHMZDOMJSG42DSNZVGQ>.
You are receiving this because you are subscribed to this thread.Message ID: ***@***.***>

[Pyrogenez]Pyrogenez left a comment (neuroidss/FreeEEG32-beta#8)<https://github.com/neuroidss/FreeEEG32-beta/issues/8#issuecomment-2712749754>

@Relys<https://github.com/Relys> - did you get your project up and running?

—
Reply to this email directly, view it on GitHub<https://github.com/neuroidss/FreeEEG32-beta/issues/8#issuecomment-2712749754>, or unsubscribe<https://github.com/notifications/unsubscribe-auth/AS4QDH235TPE33VO6KQMLVD2T2CE7AVCNFSM6AAAAABUYP7OKSVHI2DSMVQWIX3LMV43OSLTON2WKQ3PNVWWK3TUHMZDOMJSG42DSNZVGQ>.
You are receiving this because you are subscribed to this thread.Message ID: ***@***.***>

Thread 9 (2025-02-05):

Drift?

SinanAkkoyun, 2025-02-05:
Hi! Are all amps synchronized or do they suffer from drift despite sharing the same CLK?

bermarkus, 2025-02-07:
@SinanAkkoyun The amps will be perfectly synchronized (when interconnect pins are used) so the sampling is in sync.
However, each boards data needs to be acquired separately using its own usb cable. So then a slight drift of ~1 sample will occur as the computer doesn't know how to match up the different data stream.
@dmitry-sukhoruchkin is working on creating a synced counter channel in each datastream that will solve this issue.

SinanAkkoyun, 2025-02-07:
Thank you for your response

Closed 2025-02-07.

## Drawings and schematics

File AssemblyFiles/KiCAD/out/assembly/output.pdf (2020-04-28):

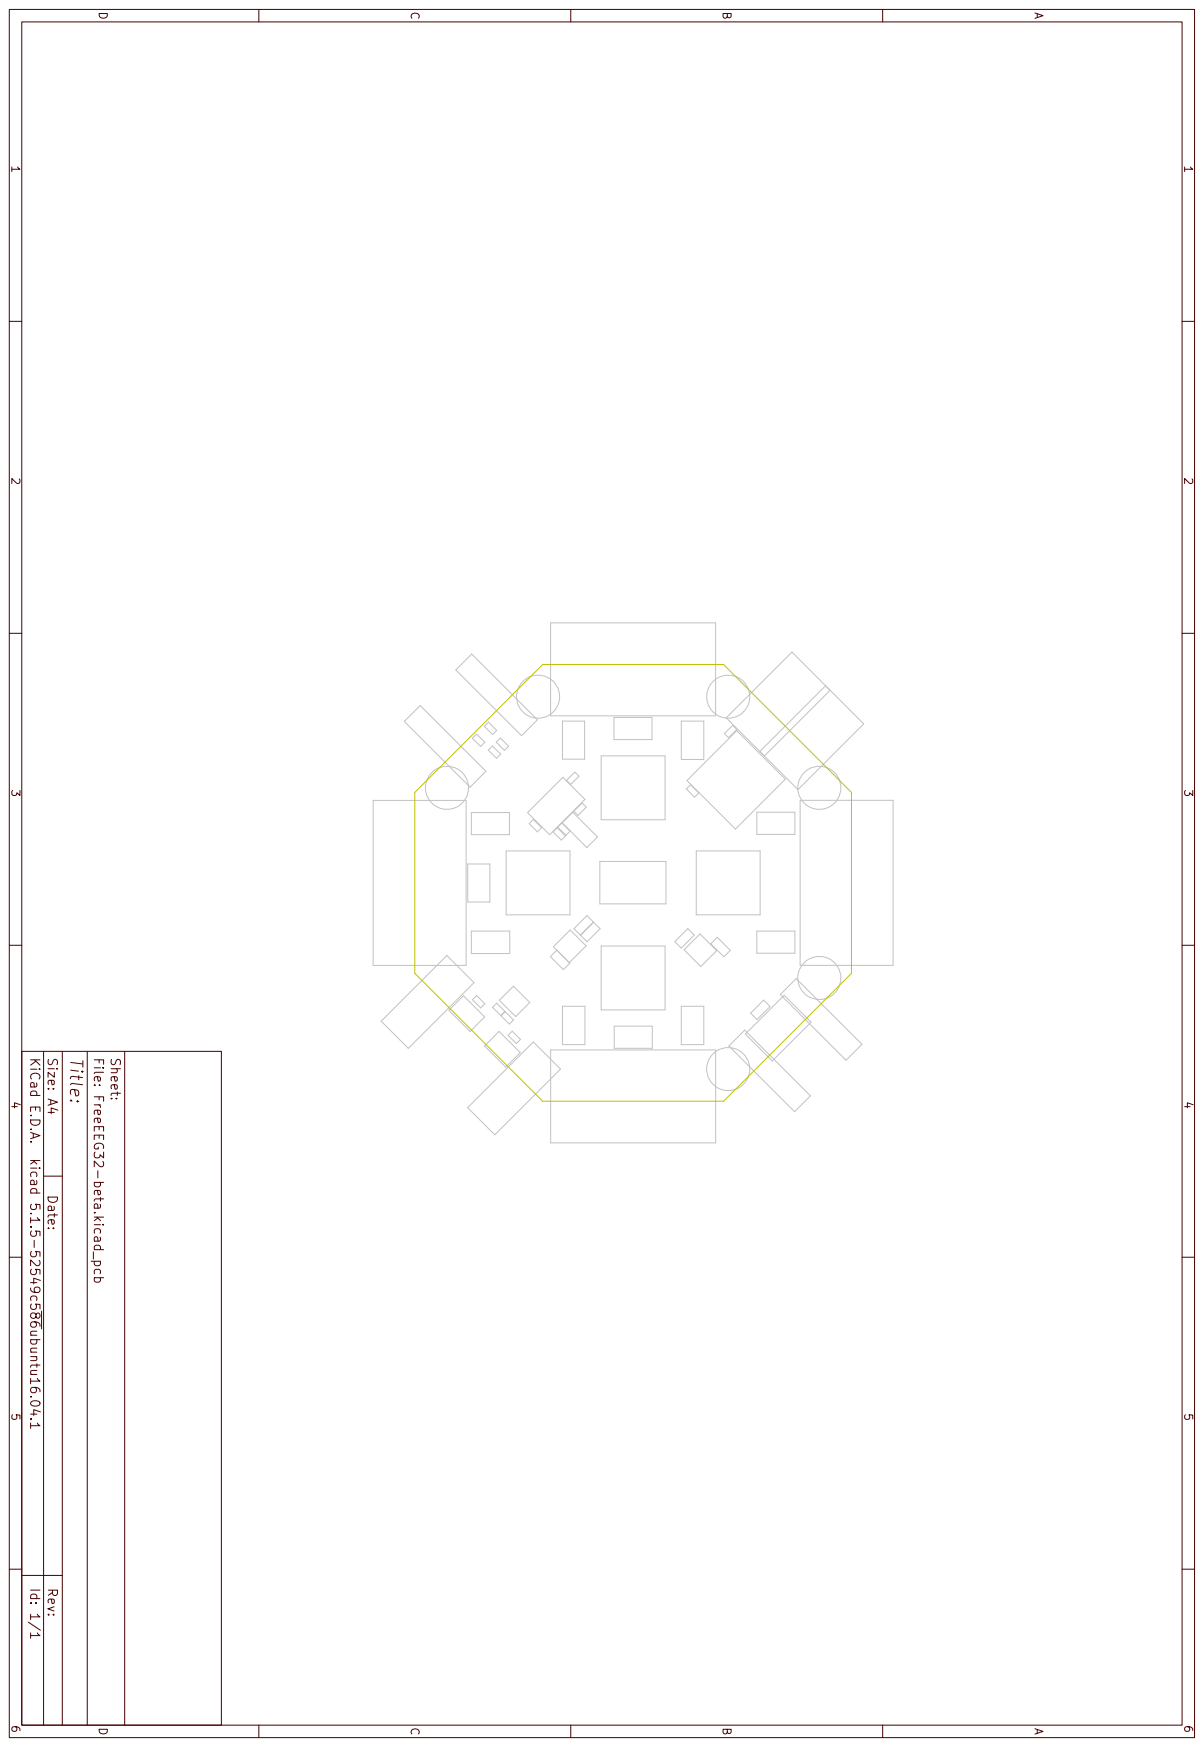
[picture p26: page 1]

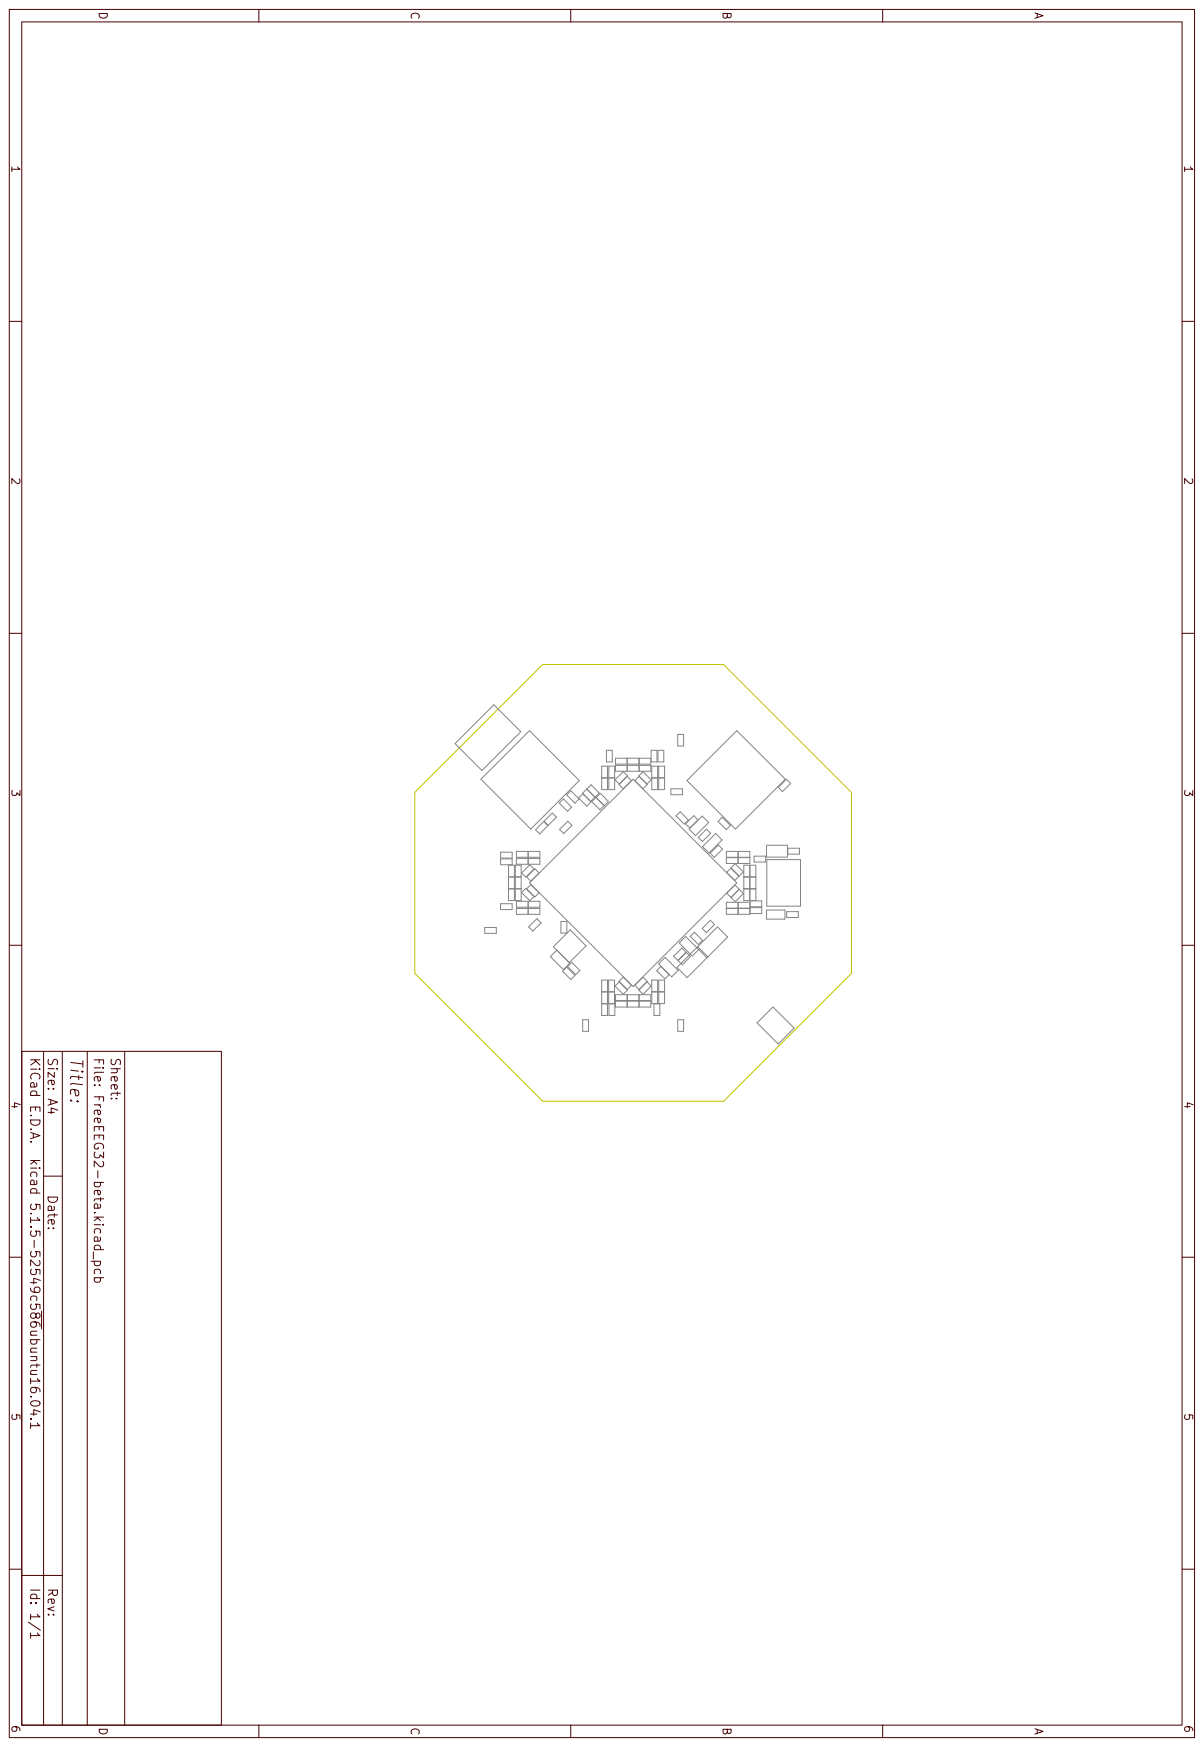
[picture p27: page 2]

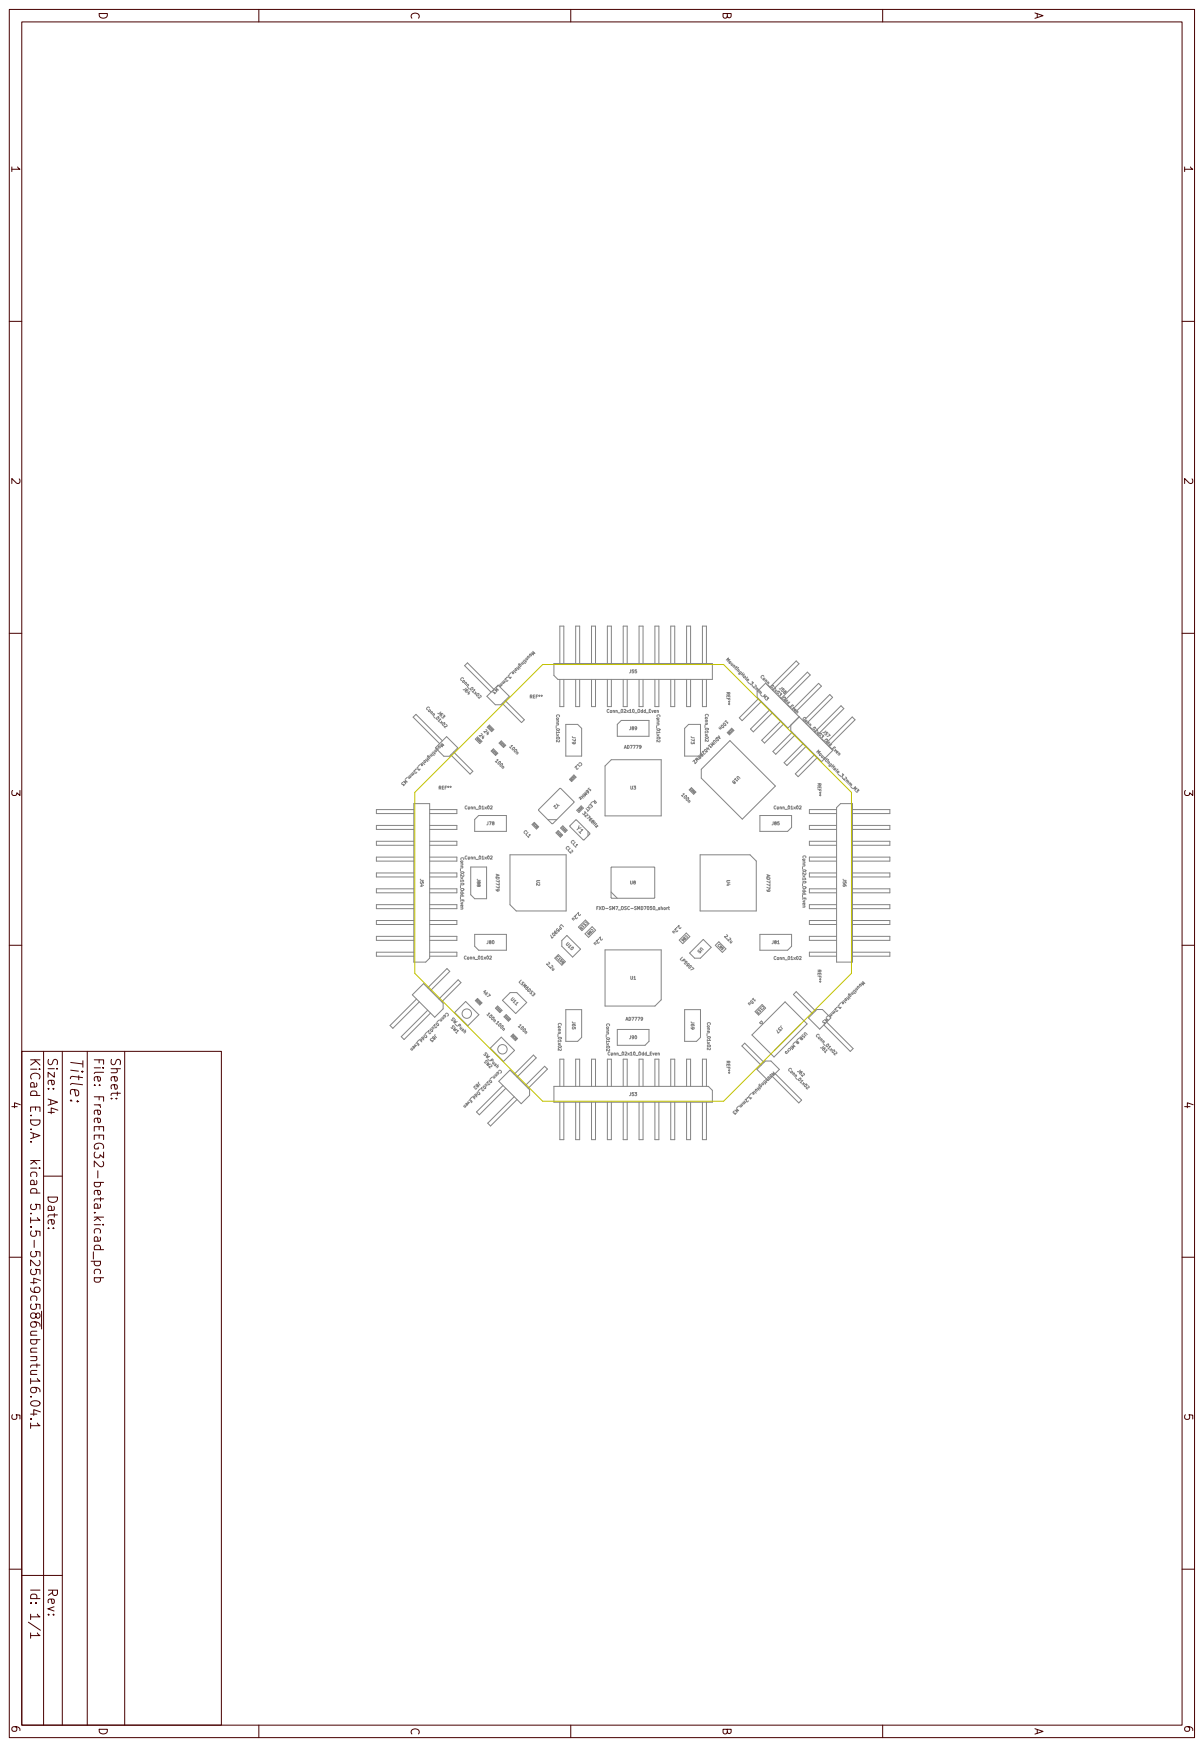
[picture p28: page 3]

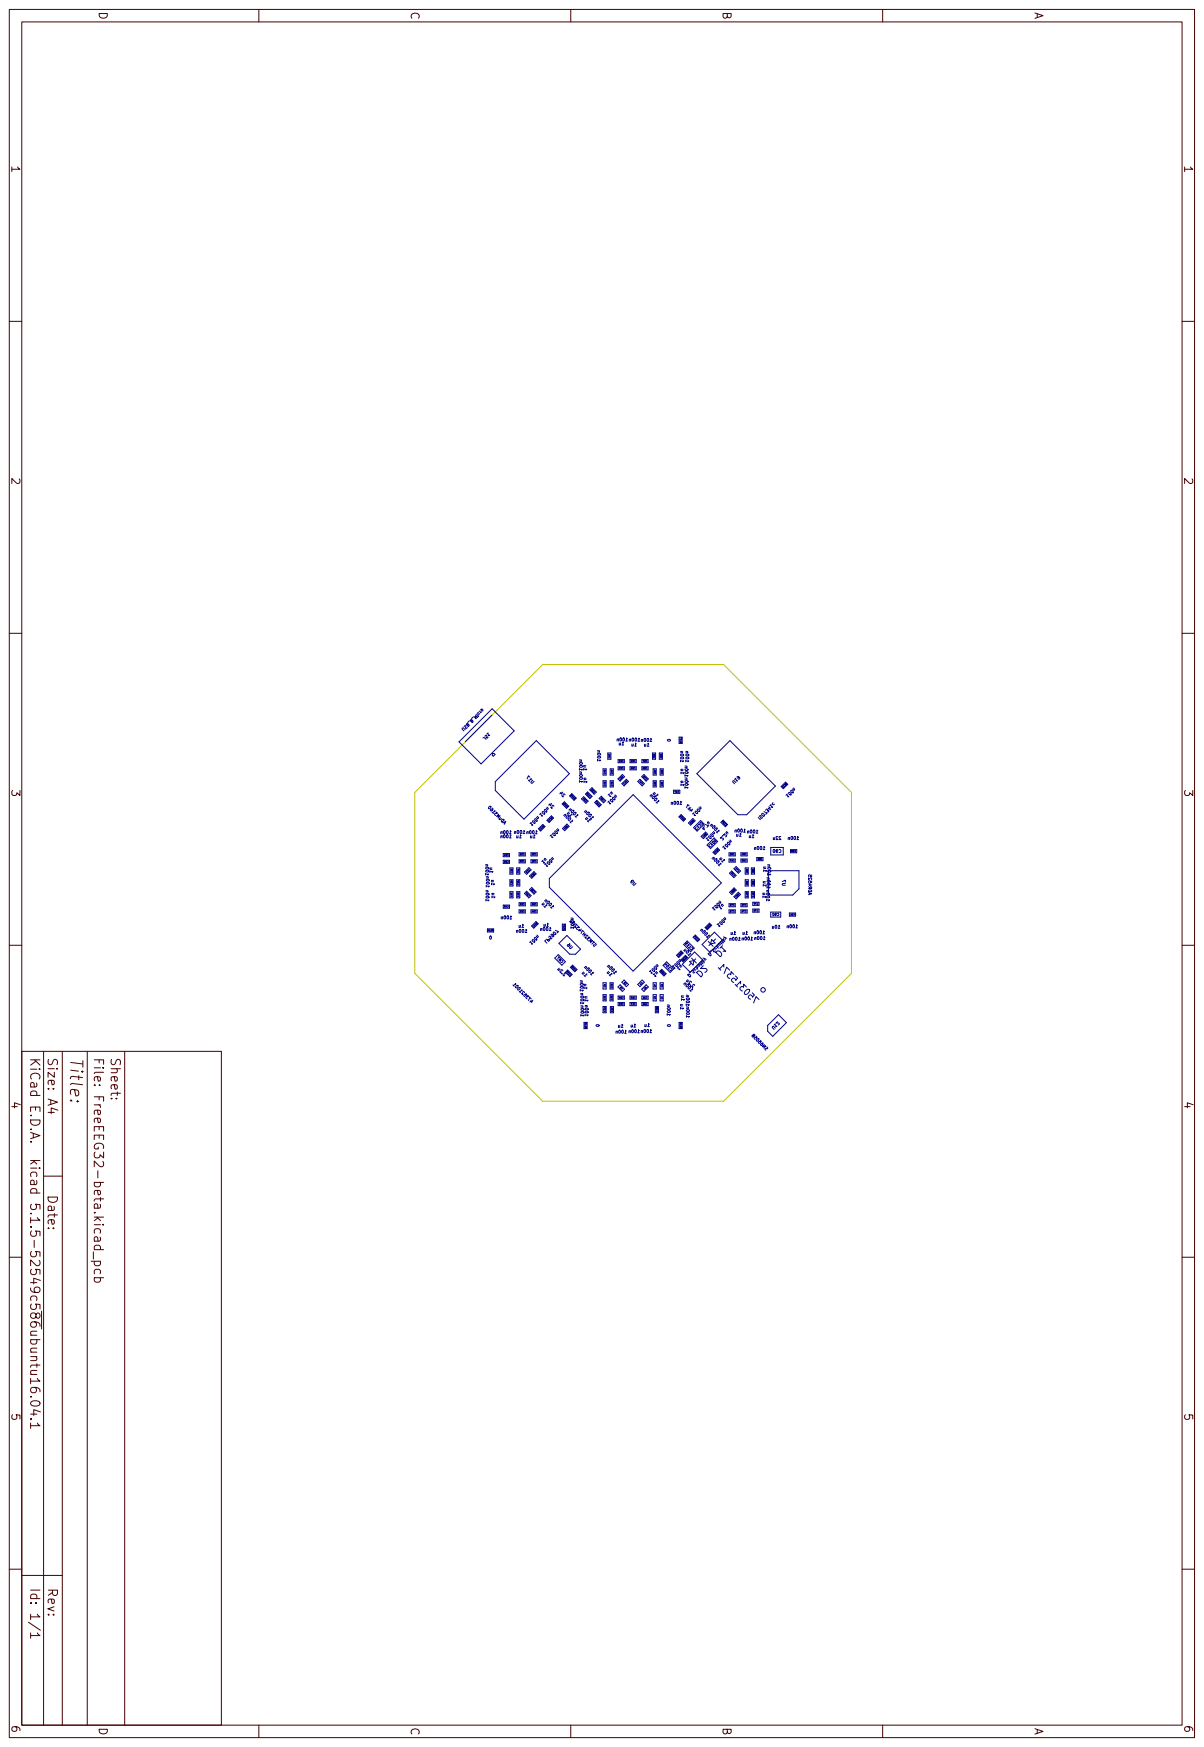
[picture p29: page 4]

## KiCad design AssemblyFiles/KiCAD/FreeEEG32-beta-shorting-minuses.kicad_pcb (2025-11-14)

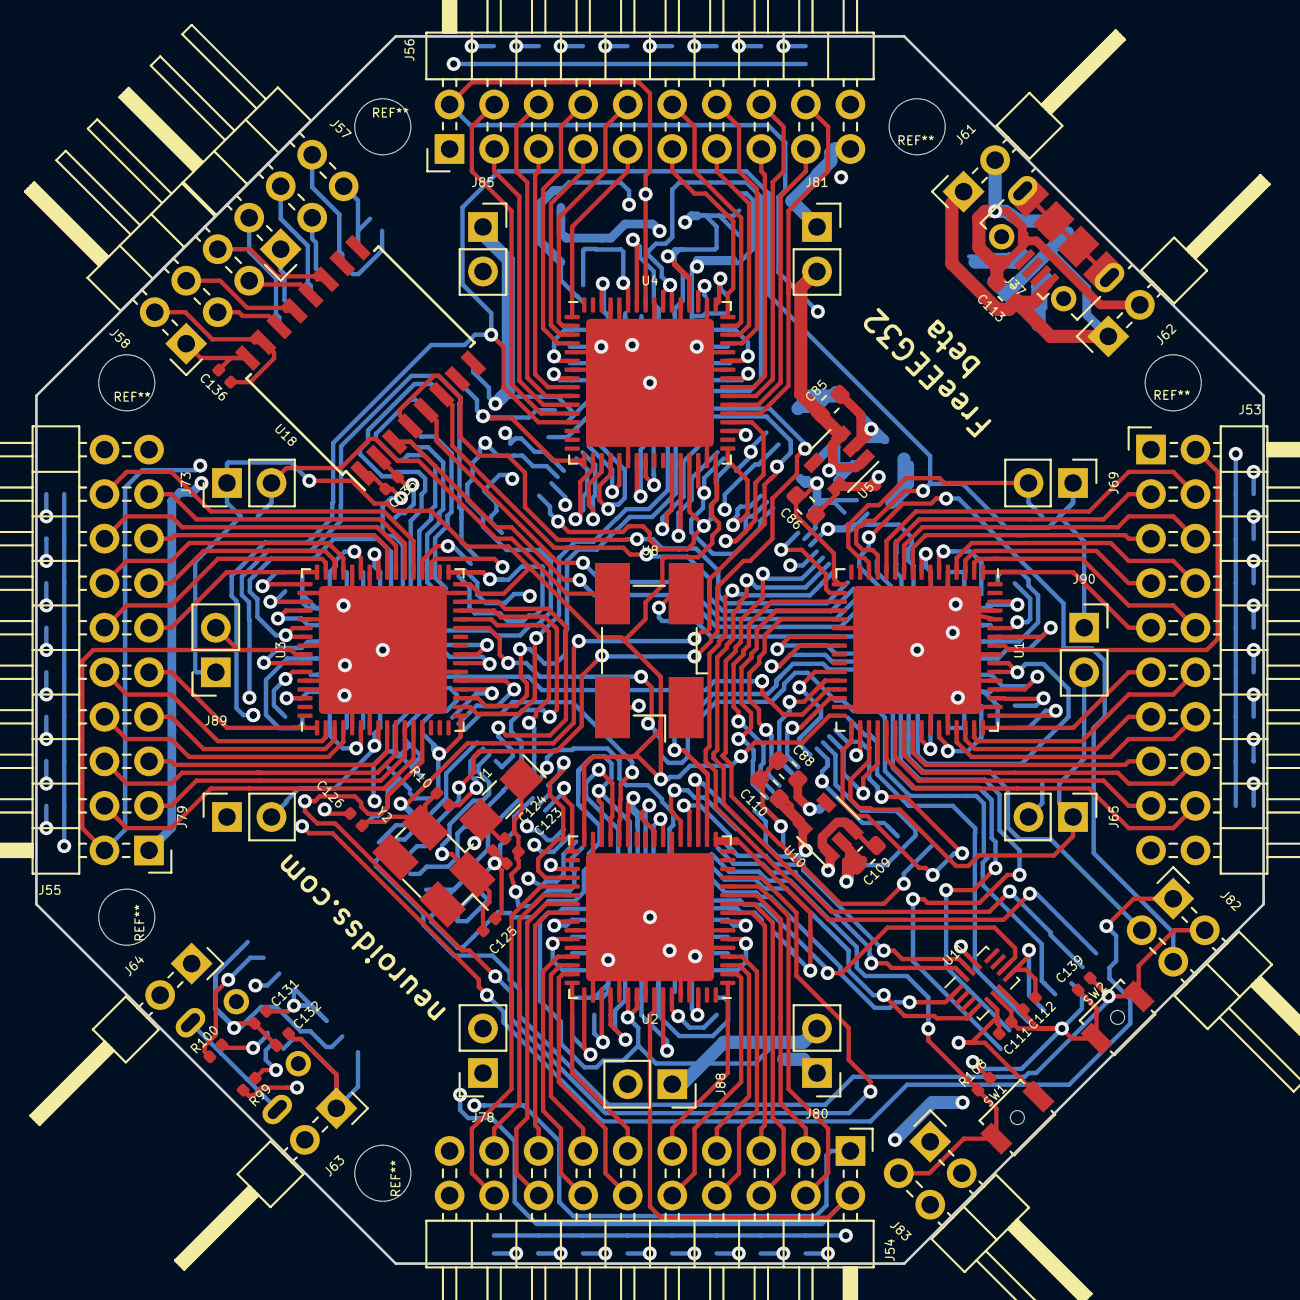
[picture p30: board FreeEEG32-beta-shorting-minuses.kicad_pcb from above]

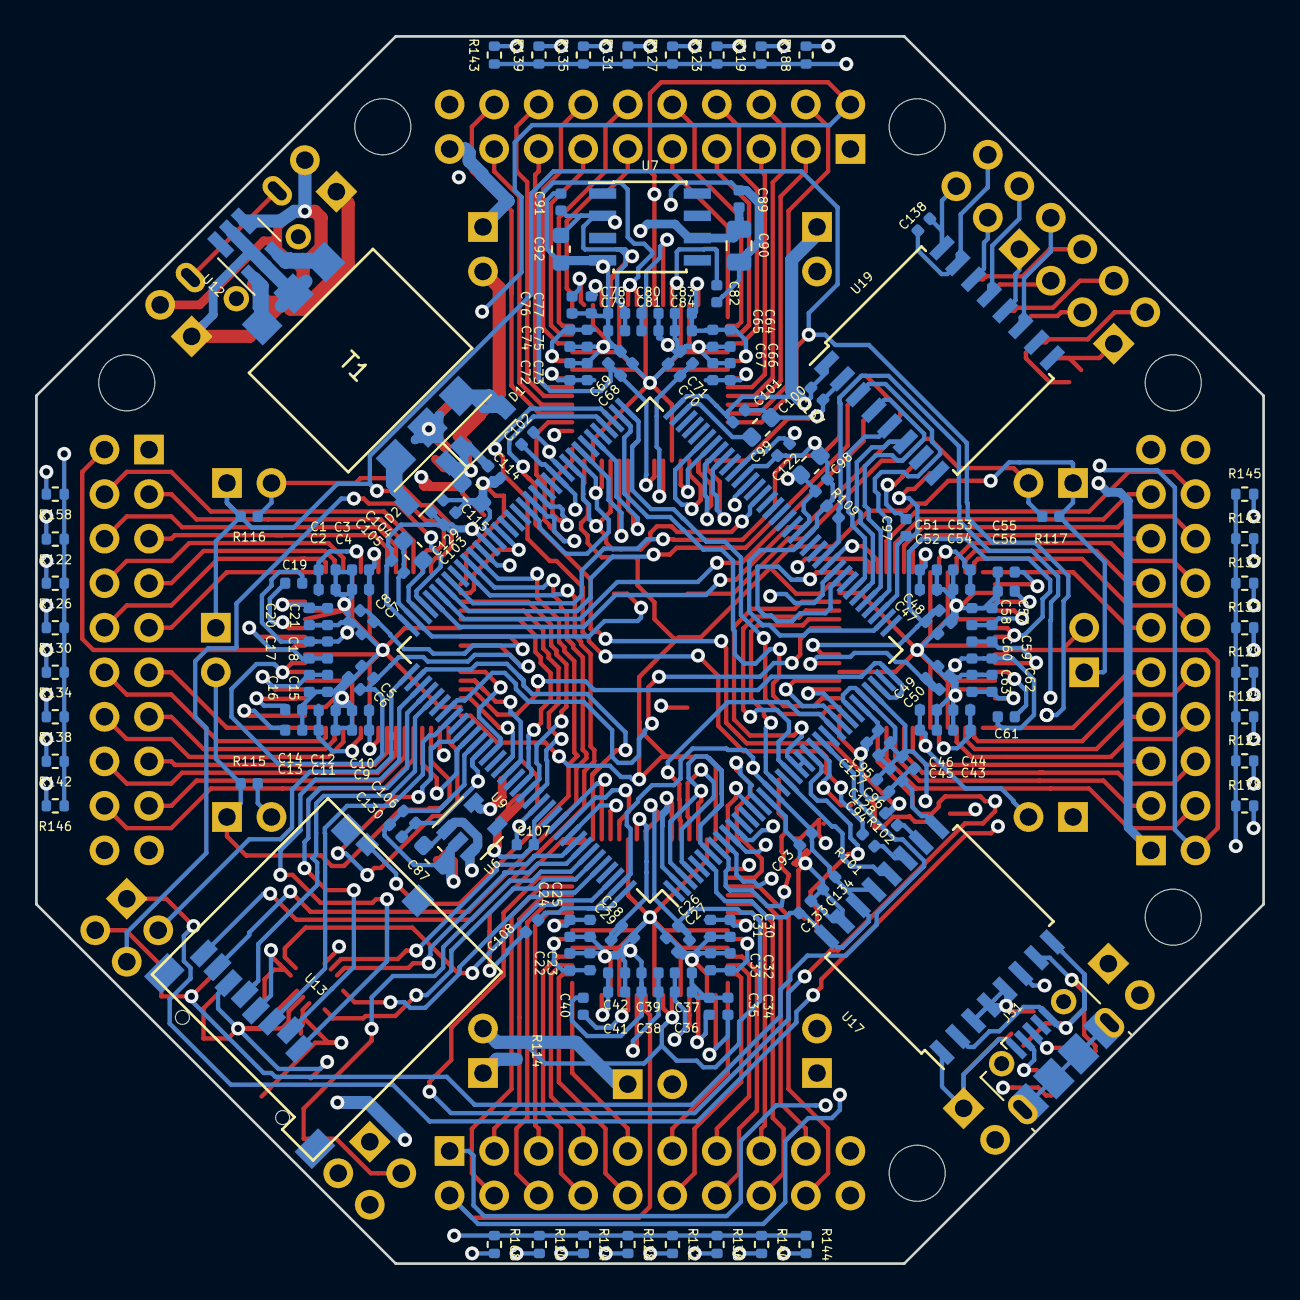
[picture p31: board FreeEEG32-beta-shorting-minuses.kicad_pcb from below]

Board: 4 copper layers, 70.0 x 70.0 mm, 224 parts (166 on the bottom side), 195 nets.

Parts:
C1, C3, C5, C7, C9, C11, C13, C14, C15, C17, C19, C20, C22, C24, C26, C28, C30, C32, C34, C35, C36, C38, C40, C41, C43, C45, C47, C49, C51, C53, C55, C56, C57, C59, C61, C62, C64, C66, C68, C70, C72, C74, C76, C77, C78, C80, C82, C83, C89, C91, C93, C94, C95, C96, C97, C98, C99, C101, C102, C103, C105, C106, C107, C108, C111, C112, C114, C131, C132, C133, C134, C135, C136, C137, C138, C139: 100n; C_0402_1005Metric
C2, C4, C6, C8, C10, C12, C16, C18, C21, C23, C25, C27, C29, C31, C33, C37, C39, C42, C44, C46, C48, C50, C52, C54, C58, C60, C63, C65, C67, C69, C71, C73, C75, C79, C81, C84, C127, C128, C129, C130: 1u; C_0402_1005Metric
C85, C86, C87, C88, C100, C104, C109, C110: 2.2u; C_0603_1608Metric
C90: 22u; C_0805_2012Metric
C92, C113, C115: 10u; C_0603_1608Metric
C122: 4.7u; C_0603_1608Metric
C123, C125: CL1; C_0402_1005Metric
C124, C126: CL2; C_0402_1005Metric
D1, D2: D_Schottky; D_SOD-123
J37, J51: USB_B_Micro; USB_Micro-B_Molex-105017-0001
J53, J54, J55, J56: Conn_02x10_Odd_Even; PinHeader_2x10_P2.54mm_Horizontal
J57, J58: Conn_02x03_Odd_Even; PinHeader_2x03_P2.54mm_Horizontal
J61, J62, J63, J64: Conn_01x02; PinHeader_2x01_P2.54mm_Horizontal
J65, J69, J73, J80: Conn_01x02; PinHeader_1x02_P2.54mm_Vertical
J78, J79, J81, J85, J88, J89, J90: Conn_01x02; PinSocket_1x02_P2.54mm_Vertical
J82, J83: Conn_02x02_Odd_Even; PinHeader_2x02_P2.54mm_Horizontal
R10: R_EXT; R_0402_1005Metric
R99, R100, R101, R102: 24; R_0402_1005Metric
R108, R109: 4k7; R_0402_1005Metric
R114, R115, R116, R117, R119, R120, R121, R122, R123, R124, R125, R126, R127, R128, R129, R130, R131, R132, R133, R134, R135, R136, R137, R138, R139, R140, R141, R142, R143, R144, R145, R146, R158, R168, R178, R188: 0; R_0402_1005Metric
SW1, SW2: SW_Push; SW_SPST_B3U-1000P-B
T1: 750315371
U1, U2, U3, U4: AD7779; QFN-64-1EP_9x9mm_P0.5mm_EP7.3x7.3mm
U5, U6, U10: LP5907; SOT-23-5
U7: ADR4525; SOIC-8_3.9x4.9mm_P1.27mm
U8: FXO-SM7_OSC-SMD7050_short; Oscillator_SMD_EuroQuartz_XO91-4Pin_7.0x5.0mm_HandSoldering
U9: STM32H743ZITx; LQFP-144_20x20mm_P0.5mm
U11: LSM6DS3; Bosch_LGA-14_3x2.5mm_P0.5mm
U12: SN6505B; SOT-23-6_Handsoldering
U13: 473521001
U17: ADuM3160; SOIC-16W_7.5x10.3mm_P1.27mm
U18: ADUM1402BRWZ; SOIC-16W_7.5x10.3mm_P1.27mm
U19: ISO7341c; SOIC-16W_7.5x10.3mm_P1.27mm
Y1: 32768Hz; Crystal_SMD_EuroQuartz_EQ161-2Pin_3.2x1.5mm_HandSoldering
Y2: 16MHz; Crystal_SMD_EuroQuartz_MJ-4Pin_5.0x3.2mm_HandSoldering

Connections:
/ADC1/1_AIN0-: J53.9, R130.2, U1.1 (AIN0-)
/ADC1/2_AIN0+: J53.10, U1.2 (AIN0+)
/ADC1/3_AIN1-: J53.7, R126.2, U1.3 (AIN1-)
/ADC1/4_AIN1+: J53.8, U1.4 (AIN1+)
/ADC1/9_AIN2-: J53.5, R122.2, U1.9 (AIN2-)
/ADC1/10_AIN2+: J53.6, U1.10 (AIN2+)
/ADC1/11_AIN3-: J53.3, R158.2, U1.11 (AIN3-)
/ADC1/12_AIN3+: J53.4, U1.12 (AIN3+)
/ADC1/37_AIN7+: J53.18, U1.37 (AIN7+)
/ADC1/38_AIN7-: J53.17, R146.2, U1.38 (AIN7-)
/ADC1/39_AIN6+: J53.16, U1.39 (AIN6+)
/ADC1/40_AIN6-: J53.15, R142.2, U1.40 (AIN6-)
/ADC1/45_AIN5+: J53.14, U1.45 (AIN5+)
/ADC1/46_AIN5-: J53.13, R138.2, U1.46 (AIN5-)
/ADC1/47_AIN4+: J53.12, U1.47 (AIN4+)
/ADC1/48_AIN4-: J53.11, R134.2, U1.48 (AIN4-)
/ADC1/49_REF_OUT: C13.1, U1.49 (REF_OUT)
/ADC1/51_AREG2CAP: C14.1, U1.51 (AREG2CAP)
/ADC1/59_AREG1CAP: C19.1, U1.59 (AREG1CAP)
/ADC2/1_AIN0-: J54.9, R128.2, U2.1 (AIN0-)
/ADC2/2_AIN0+: J54.10, U2.2 (AIN0+)
/ADC2/3_AIN1-: J54.7, R124.2, U2.3 (AIN1-)
/ADC2/4_AIN1+: J54.8, U2.4 (AIN1+)
/ADC2/9_AIN2-: J54.5, R120.2, U2.9 (AIN2-)
/ADC2/10_AIN2+: J54.6, U2.10 (AIN2+)
/ADC2/11_AIN3-: J54.3, R168.2, U2.11 (AIN3-)
/ADC2/12_AIN3+: J54.4, U2.12 (AIN3+)
/ADC2/37_AIN7+: J54.18, U2.37 (AIN7+)
/ADC2/38_AIN7-: J54.17, R144.2, U2.38 (AIN7-)
/ADC2/39_AIN6+: J54.16, U2.39 (AIN6+)
/ADC2/40_AIN6-: J54.15, R140.2, U2.40 (AIN6-)
/ADC2/45_AIN5+: J54.14, U2.45 (AIN5+)
/ADC2/46_AIN5-: J54.13, R136.2, U2.46 (AIN5-)
/ADC2/47_AIN4+: J54.12, U2.47 (AIN4+)
/ADC2/48_AIN4-: J54.11, R132.2, U2.48 (AIN4-)
/ADC2/49_REF_OUT: C34.1, U2.49 (REF_OUT)
/ADC2/51_AREG2CAP: C35.1, U2.51 (AREG2CAP)
/ADC2/59_AREG1CAP: C40.1, U2.59 (AREG1CAP)
/ADC3/1_AIN0-: J55.9, R129.2, U3.1 (AIN0-)
/ADC3/2_AIN0+: J55.10, U3.2 (AIN0+)
/ADC3/3_AIN1-: J55.7, R125.2, U3.3 (AIN1-)
/ADC3/4_AIN1+: J55.8, U3.4 (AIN1+)
/ADC3/9_AIN2-: J55.5, R121.2, U3.9 (AIN2-)
/ADC3/10_AIN2+: J55.6, U3.10 (AIN2+)
/ADC3/11_AIN3-: J55.3, R178.2, U3.11 (AIN3-)
/ADC3/12_AIN3+: J55.4, U3.12 (AIN3+)
/ADC3/37_AIN7+: J55.18, U3.37 (AIN7+)
/ADC3/38_AIN7-: J55.17, R145.2, U3.38 (AIN7-)
/ADC3/39_AIN6+: J55.16, U3.39 (AIN6+)
/ADC3/40_AIN6-: J55.15, R141.2, U3.40 (AIN6-)
/ADC3/45_AIN5+: J55.14, U3.45 (AIN5+)
/ADC3/46_AIN5-: J55.13, R137.2, U3.46 (AIN5-)
/ADC3/47_AIN4+: J55.12, U3.47 (AIN4+)
/ADC3/48_AIN4-: J55.11, R133.2, U3.48 (AIN4-)
/ADC3/49_REF_OUT: C55.1, U3.49 (REF_OUT)
/ADC3/51_AREG2CAP: C56.1, U3.51 (AREG2CAP)
/ADC3/59_AREG1CAP: C61.1, U3.59 (AREG1CAP)
/ADC4/37_AIN7+: J56.18, U4.37 (AIN7+)
/ADC4/38_AIN7-: J56.17, R143.2, U4.38 (AIN7-)
/ADC4/39_AIN6+: J56.16, U4.39 (AIN6+)
/ADC4/40_AIN6-: J56.15, R139.2, U4.40 (AIN6-)
/ADC4/45_AIN5+: J56.14, U4.45 (AIN5+)
/ADC4/46_AIN5-: J56.13, R135.2, U4.46 (AIN5-)
/ADC4/47_AIN4+: J56.12, U4.47 (AIN4+)
/ADC4/48_AIN4-: J56.11, R131.2, U4.48 (AIN4-)
/ADC4/49_REF_OUT: C76.1, U4.49 (REF_OUT)
/ADC4/51_AREG2CAP: C77.1, U4.51 (AREG2CAP)
/ADC4/59_AREG1CAP: C82.1, U4.59 (AREG1CAP)
/MCU/8_PC14: C123.1, U9.8 (PC14), Y1.1
/MCU/9_PC15: C124.1, U9.9 (PC15), Y1.2
/MCU/23_PH0: C125.1, U9.88 (PG3), Y2.1
/MCU/24_PH1: R10.1, U9.89 (PG4)
/MCU/106_VCAP_2: C104.1, U9.143 (PDR_ON)
ACC_1_SDO_SAO: U9.140 (PB9), U11.1 (SDO/SA0)
ACC_4_INT1: U9.139 (PB8), U11.4 (INT1)
ACC_9_INT2: U9.58 (PE7), U11.9 (INT2)
ACC_12_CS: C93.1, C94.1, C95.1, C96.1, C97.1, C98.1, C99.1, C101.1, C102.1, C103.1, C105.1, C106.1, C107.1, C108.1, C110.1, C111.1, C112.1, C122.1, C127.1, C128.1, C129.1, C130.1, C133.1, C134.1, C135.1, C137.1, J83.1, J85.1, SW1.1, U9.6 (VBAT), U9.17 (VDD), U9.30 (VDD), U9.39 (VDD), U9.52 (VDD), U9.62 (VDD), U9.72 (VDD), U9.84 (VDD), U9.95 (VDD33_USB), U9.108 (VDD), U9.121 (VDD), U9.131 (VDD), U9.144 (VDD), U10.5 (OUT), U11.5 (VDDIO), U11.8 (VDD), U11.12 (CS), U13.4 (VDD), U17.13 (SPD), U17.14 (VDD2), U17.16 (VBUS2), U18.1 (VCC1), U19.1 (VCC1)
ACC_13_SCL: U9.136 (PB6), U11.13 (SCL)
ACC_14_SDA: U9.137 (PB7), U11.14 (SDA)
ADC1_13_MODE0_GPIO0: J69.1, J90.1, R116.2, U1.13 (MODE0/GPIO0), U2.13 (MODE0/GPIO0), U3.13 (MODE0/GPIO0), U4.13 (MODE0/GPIO0)
ADC1_14_MODE1_GPIO1: J69.2, R116.1, U1.14 (MODE1/GPIO1)
ADC1_18_ALERT_CS: U1.18 (ALERT/CS), U9.129 (PG14)
ADC1_19_DCLK2_SCLK: U1.19 (DCLK2/SCLK), U9.12 (PF2)
ADC1_20_DCLK1_SDI: U1.20 (DCLK1/SDI), U9.13 (PF3)
ADC1_21_DCLK0_SDO: U1.21 (DCLK0/SDO), U9.11 (PF1)
ADC1_23_DREGCAP: C7.2, C8.2, U1.23 (DREGCAP)
ADC1_24_IOVDD: C5.2, C6.2, C26.2, C27.2, C47.2, C48.2, C68.2, C69.2, C88.1, J80.2, J88.1, R114.1, U1.24 (IOVDD), U1.54 (FORMAT1), U1.55 (FORMAT0), U2.24 (IOVDD), U2.54 (FORMAT1), U2.55 (FORMAT0), U3.24 (IOVDD), U3.54 (FORMAT1), U3.55 (FORMAT0), U4.24 (IOVDD), U4.54 (FORMAT1), U4.55 (FORMAT0), U6.5 (OUT)
ADC1_27_DOUT1: U1.27 (DOUT1), U9.122 (PD6)
ADC1_29_DCLK: U1.29 (DCLK), U9.34 (PA0), U9.36 (PA2)
ADC1_30_DRDY: U1.30 (DRDY), U9.46 (PB0), U9.96 (PC6), U9.132 (PG15)
ADC1_32_XTAL2_MCLK: J73.1, J89.1, R117.2, U1.32 (XTAL2/MCLK), U2.32 (XTAL2/MCLK), U3.32 (XTAL2/MCLK), U4.32 (XTAL2/MCLK)
ADC1_33_START: U1.33 (START), U9.118 (PD4)
ADC1_34_SYNC_OUT: J65.2, R115.1, U1.34 (SYNC_OUT)
ADC1_35_SYNC_IN: J65.1, J90.2, R115.2, U1.35 (SYNC_IN), U2.35 (SYNC_IN), U3.35 (SYNC_IN), U4.35 (SYNC_IN)
ADC1_36_RESET: U1.36 (RESET), U9.119 (PD5)
ADC1_41_REF2+: C3.2, C4.2, C9.2, C10.2, C24.2, C25.2, C30.2, C31.2, C45.2, C46.2, C51.2, C52.2, C66.2, C67.2, C72.2, C73.2, C89.1, C90.1, J79.2, U1.8 (REF1+), U1.41 (REF2+), U2.8 (REF1+), U2.41 (REF2+), U3.8 (REF1+), U3.41 (REF2+), U4.8 (REF1+), U4.41 (REF2+), U7.6 (VOUT)
ADC1_43_AVDD1B: C1.2, C2.2, C11.2, C12.2, C15.2, C16.2, C17.2, C18.2, C20.1, C21.1, C22.2, C23.2, C32.2, C33.2, C36.2, C37.2, C38.2, C39.2, C41.1, C42.1, C43.2, C44.2, C53.2, C54.2, C57.2, C58.2, C59.2, C60.2, C62.1, C63.1, C64.2, C65.2, C74.2, C75.2, C78.2, C79.2, C80.2, C81.2, C83.1, C84.1, C86.1, C91.1, C92.1, J53.20, J54.20, J55.20, J56.20, J85.2, U1.6 (AVDD1A), U1.43 (AVDD1B), U1.52 (AVDD2B), U1.58 (AVDD2A), U1.62 (AVDD4), U2.6 (AVDD1A), U2.43 (AVDD1B), U2.52 (AVDD2B), U2.58 (AVDD2A), U2.62 (AVDD4), U3.6 (AVDD1A), U3.43 (AVDD1B), U3.52 (AVDD2B), U3.58 (AVDD2A), U3.62 (AVDD4), U4.6 (AVDD1A), U4.43 (AVDD1B), U4.52 (AVDD2B), U4.58 (AVDD2A), U4.62 (AVDD4), U5.5 (OUT), U7.2 (VIN)
ADC1_57_VCM: J53.2, J54.2, J55.2, J56.2, J89.2, U1.57 (VCM), U2.57 (VCM), U3.57 (VCM), U4.57 (VCM)
ADC2_18_ALERT_CS: U2.18 (ALERT/CS), U9.110 (PA15)
ADC2_19_DCLK2_SCLK: U2.19 (DCLK2/SCLK), U9.133 (PB3)
ADC2_20_DCLK1_SDI: U2.20 (DCLK1/SDI), U9.135 (PB5)
ADC2_21_DCLK0_SDO: U2.21 (DCLK0/SDO), U9.134 (PB4)
ADC2_23_DREGCAP: C28.2, C29.2, U2.23 (DREGCAP)
ADC2_27_DOUT1: U2.27 (DOUT1), U9.60 (PE9)
ADC2_28_DOUT0: U2.28 (DOUT0), U9.27 (PC1)
ADC2_29_DCLK: U2.29 (DCLK), U9.64 (PE11)
ADC2_30_DRDY: U2.30 (DRDY), U9.7 (PC13), U9.63 (PE10)
ADC2_33_START: U2.33 (START), U9.22 (PF10)
ADC2_36_RESET: U2.36 (RESET), U9.49 (PF11)
ADC3_18_ALERT_CS: U3.18 (ALERT/CS), U9.73 (PB12)
ADC3_19_DCLK2_SCLK: U3.19 (DCLK2/SCLK), U9.74 (PB13)
ADC3_20_DCLK1_SDI: U3.20 (DCLK1/SDI), U9.29 (PC3_C)
ADC3_21_DCLK0_SDO: U3.21 (DCLK0/SDO), U9.28 (PC2_C)
ADC3_23_DREGCAP: C49.2, C50.2, U3.23 (DREGCAP)
ADC3_27_DOUT1: U3.27 (DOUT1), U9.115 (PD1)
ADC3_28_DOUT0: U3.28 (DOUT0), U9.50 (PF12)
ADC3_29_DCLK: U3.29 (DCLK), U9.54 (PF14)
ADC3_30_DRDY: U3.30 (DRDY), U9.55 (PF15)
ADC3_33_START: U3.33 (START), U9.45 (PC5)
ADC3_36_RESET: U3.36 (RESET), U9.47 (PB1)
ADC4_18_ALERT_CS: U4.18 (ALERT/CS), U9.71 (VCAP)
ADC4_19_DCLK2_SCLK: U4.19 (DCLK2/SCLK), U9.106 (VCAP)
ADC4_23_DREGCAP: C70.2, C71.2, U4.23 (DREGCAP)
ADC4_27_DOUT1: U4.27 (DOUT1), U9.78 (PD9)
ADC4_28_DOUT0: U4.28 (DOUT0), U9.80 (PD11)
ADC4_29_DCLK: U4.29 (DCLK), U9.66 (PE13), U9.82 (PD13)
ADC4_30_DRDY: U4.30 (DRDY), U9.68 (PE15), U9.81 (PD12), U9.125 (PG10)
ADC4_33_START: U4.33 (START), U9.93 (PG8)
ADC4_36_RESET: U4.36 (RESET), U9.124 (PG9)
ADC4_AIN0+: J56.10, U4.2 (AIN0+)
ADC4_AIN0-: J56.9, R127.2, U4.1 (AIN0-)
ADC4_AIN1+: J56.8, U4.4 (AIN1+)
ADC4_AIN1-: J56.7, R123.2, U4.3 (AIN1-)
ADC4_AIN2+: J56.6, U4.10 (AIN2+)
ADC4_AIN2-: J56.5, R119.2, U4.9 (AIN2-)
ADC4_AIN3+: J56.4, U4.12 (AIN3+)
ADC4_AIN3-: J56.3, R188.2, U4.11 (AIN3-)
AINREF-: J53.1, J54.1, J55.1, J56.1, J88.2, R119.1, R120.1, R121.1, R122.1, R123.1, R124.1, R125.1, R126.1, R127.1, R128.1, R129.1, R130.1, R131.1, R132.1, R133.1, R134.1, R135.1, R136.1, R137.1, R138.1, R139.1, R140.1, R141.1, R142.1, R143.1, R144.1, R145.1, R146.1, R158.1, R168.1, R178.1, R188.1
AVDD_1_IN: C85.1, C87.1, C109.1, C114.1, C115.1, D1.1 (K), D2.1 (K), J81.2, J83.4, U5.1 (IN), U5.3 (EN), U6.1 (IN), U6.3 (EN), U10.1 (IN), U10.3 (EN)
CRYSTAL_3_OUT: J73.2, R117.1, U8.3 (OUT)
CRYSTAL_4_Vin: J80.1, R114.2, U8.4 (Vin)
ISO_SPI_3_INA: U9.40 (PA4), U19.3 (INA)
ISO_SPI_4_INB: U9.41 (PA5), U19.4 (INB)
ISO_SPI_5_INC: U9.43 (PA7), U19.5 (INC)
ISO_SPI_6_OUTD: U9.42 (PA6), U19.6 (OUTD)
ISO_SPI_11_IND: J57.2, U19.11 (IND)
ISO_SPI_12_OUTC: J57.1, U19.12 (OUTC)
ISO_SPI_13_OUTB: J57.4, U19.13 (OUTB)
ISO_SPI_14_OUTA: J57.3, U19.14 (OUTA)
ISO_SPI_15_GND2: C138.2, J57.6, U19.15 (GND2)
ISO_SPI_16_VCC2: C138.1, J57.5, U19.16 (VCC2)
ISO_UART_3_INA: U9.104 (PA12), U18.3 (INA)
ISO_UART_4_INB: U9.101 (PA9), U18.4 (INB)
ISO_UART_5_OUTC: U9.103 (PA11), U18.5 (OUTC)
ISO_UART_6_OUTD: U9.102 (PA10), U18.6 (OUTD)
ISO_UART_11_IND: J58.6, U18.11 (IND)
ISO_UART_12_INC: J58.5, U18.12 (INC)
ISO_UART_13_OUTB: J58.4, U18.13 (OUTB)
ISO_UART_14_OUTA: J58.3, U18.14 (OUTA)
ISO_UART_15_GND2: C136.2, J58.2, U18.15 (GND2)
ISO_UART_16_VCC2: C136.1, J58.1, U18.16 (VCC2)
ISO_USB_1_VBUS1: C132.1, J51.1 (VBUS), J63.1, U17.1 (VBUS1)
ISO_USB_3_VDD1: C131.1, U17.3 (VDD1), U17.4 (PDEN), U17.5 (SPU)
ISO_USB_6_UD–: J51.2 (D-), J64.2, R99.2
ISO_USB_7_UD+: J51.3 (D+), J64.1, R100.2
ISO_USB_8_GND1: C131.2, C132.2, J51.5 (GND), J63.2, U17.2 (GND1), U17.8 (GND1)
ISO_USB_10_DD+: R102.1, U9.76 (PB15)
ISO_USB_11_DD–: R101.1, U9.75 (PB14)
ISO_USB_12_PIN: U9.53 (PF13), U17.12 (PIN)
MCU_10_PF0_I2C2_SDA: J78.2, U9.18 (PF6)
MCU_11_PF1_I2C2_SCL: J78.1, U9.19 (PF7)
MCU_25_NRST: C139.2, J82.2, SW2.2, U9.25 (NRST)
MCU_48_PB2_BOOT1: J82.1, R109.1, U9.48 (PB2)
MCU_51_VSS: C1.1, C2.1, C3.1, C4.1, C5.1, C6.1, C7.1, C8.1, C9.1, C10.1, C11.1, C12.1, C13.2, C14.2, C15.1, C16.1, C17.1, C18.1, C19.2, C20.2, C21.2, C22.1, C23.1, C24.1, C25.1, C26.1, C27.1, C28.1, C29.1, C30.1, C31.1, C32.1, C33.1, C34.2, C35.2, C36.1, C37.1, C38.1, C39.1, C40.2, C41.2, C42.2, C43.1, C44.1, C45.1, C46.1, C47.1, C48.1, C49.1, C50.1, C51.1, C52.1, C53.1, C54.1, C55.2, C56.2, C57.1, C58.1, C59.1, C60.1, C61.2, C62.2, C63.2, C64.1, C65.1, C66.1, C67.1, C68.1, C69.1, C70.1, C71.1, C72.1, C73.1, C74.1, C75.1, C76.2, C77.2, C78.1, C79.1, C80.1, C81.1, C82.2, C83.2, C84.2, C85.2, C86.2, C87.2, C88.2, C89.2, C90.2, C91.2, C92.2, C93.2, C94.2, C95.2, C96.2, C97.2, C98.2, C99.2, C100.2, C101.2, C102.2, C103.2, C104.2, C105.2, C106.2, C107.2, C108.2, C109.2, C110.2, C111.2, C112.2, C114.2, C115.2, C122.2, C123.2, C124.2, C125.2, C126.2, C127.2, C128.2, C129.2, C130.2, C133.2, C134.2, C135.2, C137.2, C139.1, J53.19, J54.19, J55.19, J56.19, J79.1, J81.1, J83.2, R108.2, R109.2, SW2.1, T1.5, U1.5 (AVSS1A), U1.7 (REF1-), U1.17 (CONVST_SAR), U1.22 (DGND), U1.31 (XTAL1), U1.42 (REF2-), U1.44 (AVSS1B), U1.50 (AVSS2B), U1.53 (AVSS3), U1.56 (CLK_SEL), U1.60 (AVSS2A), U1.61 (AVSS4), U1.65 (EPAD), U2.5 (AVSS1A), U2.7 (REF1-), U2.17 (CONVST_SAR), U2.22 (DGND), U2.31 (XTAL1), U2.42 (REF2-), U2.44 (AVSS1B), U2.50 (AVSS2B), U2.53 (AVSS3), U2.56 (CLK_SEL), U2.60 (AVSS2A), U2.61 (AVSS4), U2.65 (EPAD), U3.5 (AVSS1A), U3.7 (REF1-), U3.17 (CONVST_SAR), U3.22 (DGND), U3.31 (XTAL1), U3.42 (REF2-), U3.44 (AVSS1B), U3.50 (AVSS2B), U3.53 (AVSS3), U3.56 (CLK_SEL), U3.60 (AVSS2A), U3.61 (AVSS4), U3.65 (EPAD), U4.5 (AVSS1A), U4.7 (REF1-), U4.17 (CONVST_SAR), U4.22 (DGND), U4.31 (XTAL1), U4.42 (REF2-), U4.44 (AVSS1B), U4.50 (AVSS2B), U4.53 (AVSS3), U4.56 (CLK_SEL), U4.60 (AVSS2A), U4.61 (AVSS4), U4.65 (EPAD), U5.2 (GND), U6.2 (GND), U7.4 (GND), U8.2 (GND), U9.16 (VSS), U9.31 (VSSA), U9.38 (VSS), U9.51 (VSS), U9.61 (VSS), U9.83 (VSS), U9.94 (VSS), U9.107 (VSS), U9.120 (VSS), U9.130 (VSS), U10.2 (GND), U11.6 (GND), U11.7 (GND), U13.6 (Vss), U17.9 (GND2), U17.15 (GND2), U18.2 (GND1), U19.2 (GND1)
MCU_97_PC7_SDMMC1_DETECT: U9.97 (PC7), U13.9 (DETECT)
MCU_98_PC8_SDMMC1_D0: U9.98 (PC8), U13.7 (DATA0)
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

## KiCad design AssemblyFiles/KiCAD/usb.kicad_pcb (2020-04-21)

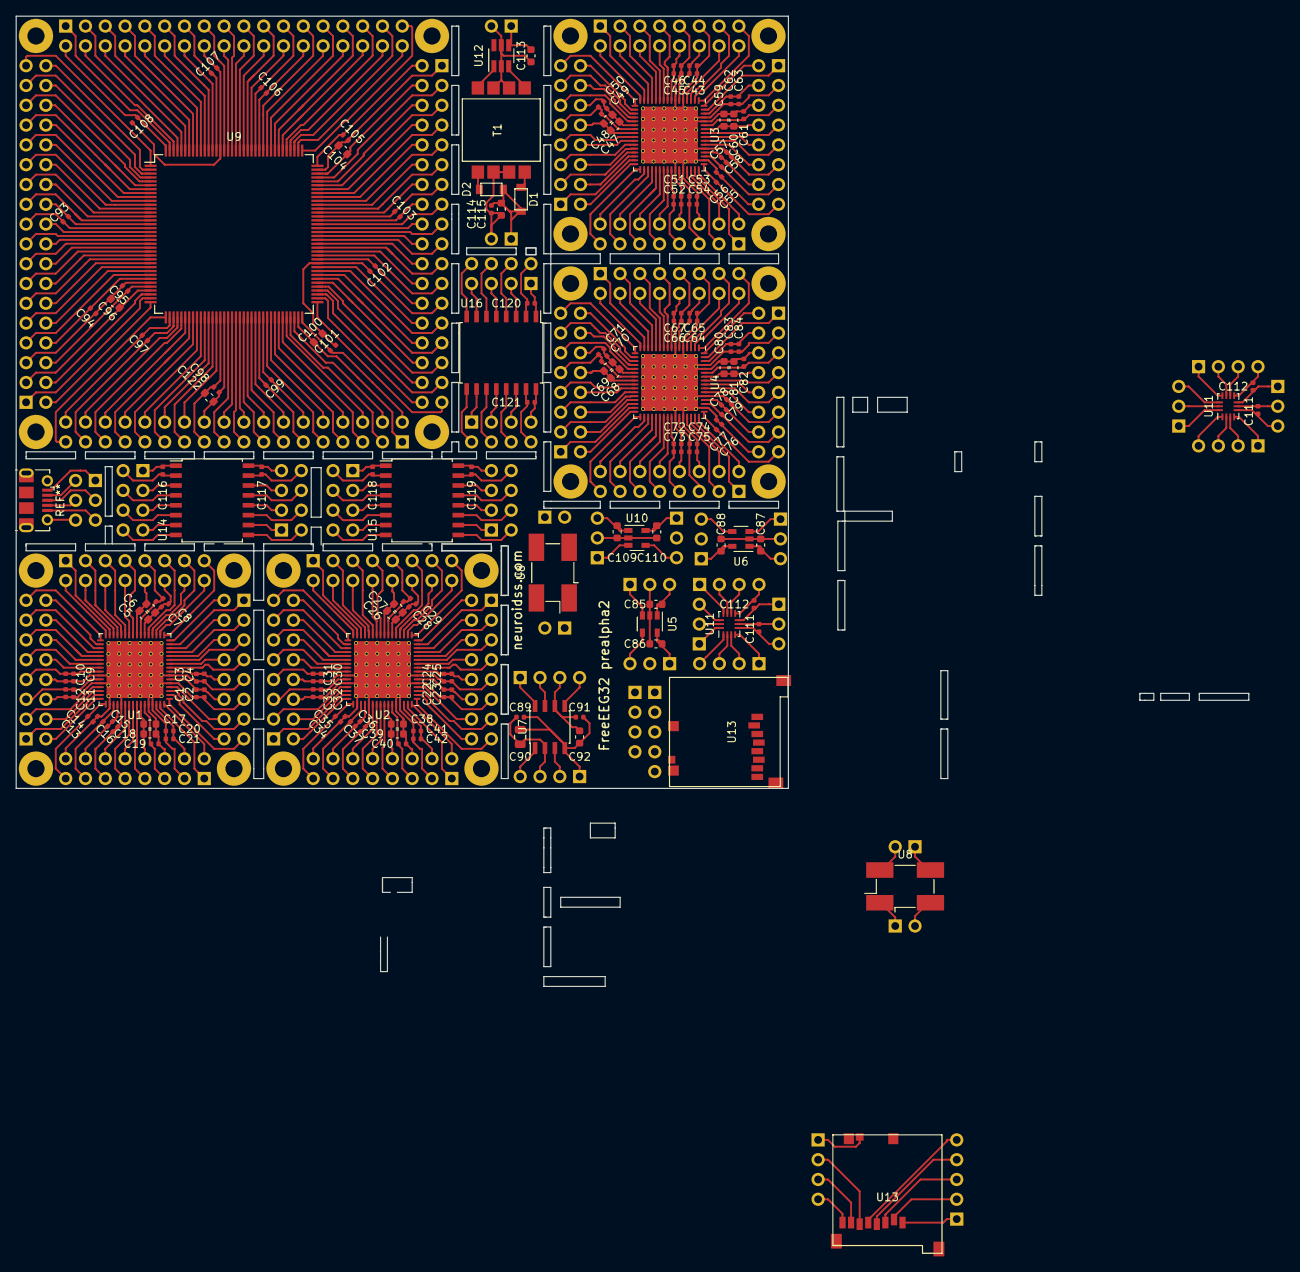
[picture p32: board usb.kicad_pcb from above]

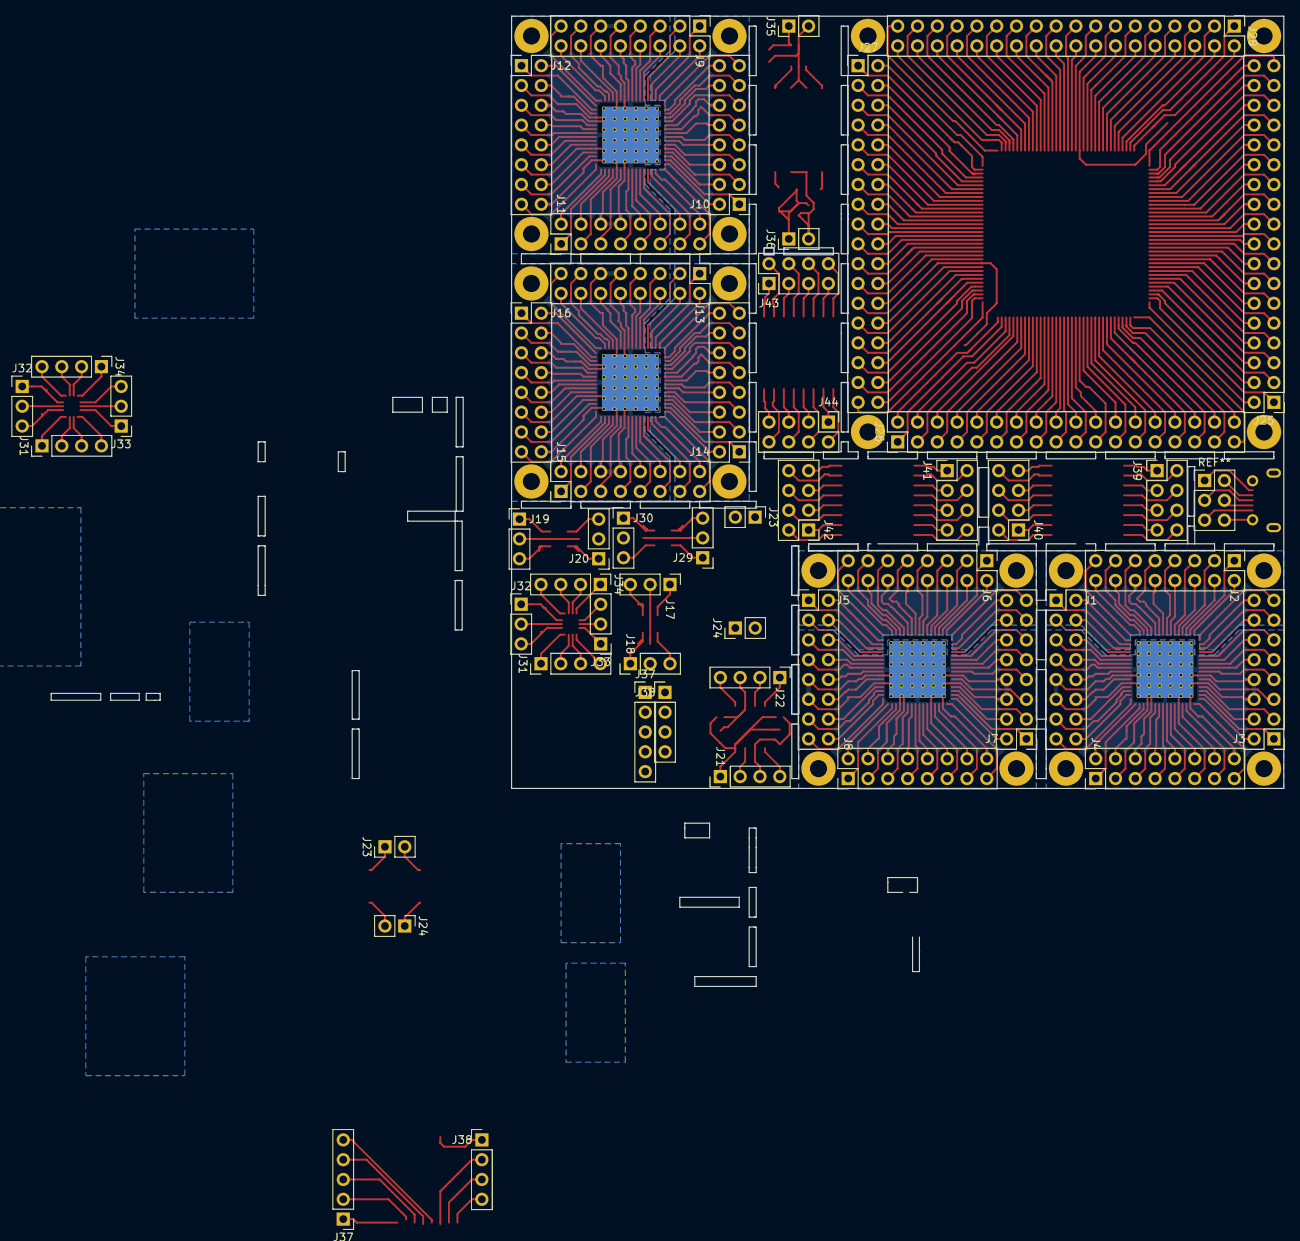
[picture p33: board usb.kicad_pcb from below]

Board: 2 copper layers, 99.1 x 99.1 mm, 198 parts (52 on the bottom side), 463 nets.

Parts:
C1, C3, C7, C9, C11, C13, C14, C15, C19, C20, C22, C24, C28, C30, C32, C34, C35, C36, C40, C41, C43, C45, C49, C51, C53, C55, C56, C57, C61, C62, C64, C66, C70, C72, C74, C76, C77, C78, C82, C83, C89, C91, C93, C94, C95, C97, C98, C99, C101, C102, C103, C105, C106, C107, C108, C111, C111#2, C112, C112#2, C114, C116, C117, C118, C119, C120, C121: 100n; C_0402_1005Metric
C2, C4, C8, C10, C12, C16, C21, C23, C25, C29, C31, C33, C37, C42, C44, C46, C50, C52, C54, C58, C63, C65, C67, C71, C73, C75, C79, C84: 1u; C_0402_1005Metric
C5, C17, C26, C38, C47, C59, C68, C80, C96: 100n; C_0603_1608Metric
C6, C18, C27, C39, C48, C60, C69, C81: 1u; C_0603_1608Metric
C85, C86, C87, C88, C100, C104, C109, C110: 2.2u; C_0603_1608Metric
C90: 22u; C_0805_2012Metric
C92, C113, C115: 10u; C_0603_1608Metric
C122: 4.7u; C_0603_1608Metric
D1, D2: D_Schottky; SOD−123
J1, J2, J3, J4, J5, J6, J7, J8, J9, J10, J11, J12, J13, J14, J15, J16: Conn_02x08_Odd_Even; PinHeader_2x08_P2.54mm_Vertical
J17, J18, J19, J20, J29, J30, J32, J32#2, J33, J33#2: Conn_01x03; PinHeader_1x03_P2.54mm_Vertical
J21, J22, J31, J31#2, J34, J34#2, J38, J38#2: Conn_01x04; PinHeader_1x04_P2.54mm_Vertical
J23, J23#2, J24, J24#2, J35, J36: Conn_01x02; PinHeader_1x02_P2.54mm_Vertical
J25, J26, J27, J28: Conn_02x18_Odd_Even; PinHeader_2x18_P2.54mm_Vertical
J37, J37#2: Conn_01x05; PinHeader_1x05_P2.54mm_Vertical
J39, J40, J41, J42, J43, J44: Conn_02x04_Odd_Even; PinHeader_2x04_P2.54mm_Vertical
T1: da2303; SMT Power Transformer
U1, U2, U3, U4: AD7779; QFN-64-1EP_9x9mm_P0.5mm_EP7.3x7.3mm_ThermalVias
U5, U6, U10: LP5907; SOT-23-5
U7: ADR4525; SOIC-8_3.9x4.9mm_P1.27mm
U8, U8#2: FXO-SM7_OSC-SMD7050_short; Oscillator_SMD_EuroQuartz_XO91-4Pin_7.0x5.0mm_HandSoldering
U9: STM32F765ZITx; LQFP-144_20x20mm_P0.5mm
U11, U11#2: LSM6DS3; Bosch_LGA-14_3x2.5mm_P0.5mm
U12: SN6505A; SOT-23-6_Handsoldering
U13, U13#2: 473521001
U14, U15, U16: ISO7341c; SOIC-16W_7.5x10.3mm_P1.27mm

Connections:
/ACCEL&GYRO/1: J31.4, J31#2.4, U11.1, U11#2.1
/ACCEL&GYRO/2: J31.3, J31#2.3, U11.2, U11#2.2
/ACCEL&GYRO/3: J31.2, J31#2.2, U11.3, U11#2.3
/ACCEL&GYRO/4: J31.1, J31#2.1, U11.4, U11#2.4
/ACCEL&GYRO/5: C111.1, C111#2.1, J32.3, J32#2.3, U11.5, U11#2.5
/ACCEL&GYRO/6: C111.2, C111#2.2, J32.2, J32#2.2, U11.6, U11#2.6
/ACCEL&GYRO/7: C112.2, C112#2.2, J32.1, J32#2.1, U11.7, U11#2.7
/ACCEL&GYRO/8: C112.1, C112#2.1, J34.4, J34#2.4, U11.8, U11#2.8
/ACCEL&GYRO/9: J34.3, J34#2.3, U11.9, U11#2.9
/ACCEL&GYRO/10: J34.2, J34#2.2, U11.10, U11#2.10
/ACCEL&GYRO/11: J34.1, J34#2.1, U11.11, U11#2.11
/ACCEL&GYRO/12: J33.3, J33#2.3, U11.12, U11#2.12
/ACCEL&GYRO/13: J33.2, J33#2.2, U11.13, U11#2.13
/ACCEL&GYRO/14: J33.1, J33#2.1, U11.14, U11#2.14
/ADC1/1: J1.15, U1.1
/ADC1/2: J1.16, U1.2
/ADC1/3: J1.13, U1.3
/ADC1/4: J1.14, U1.4
/ADC1/6: C1.2, C2.2, J1.12, U1.6
/ADC1/8: C3.2, C4.2, J1.10, U1.8
/ADC1/9: J1.7, U1.9
/ADC1/10: J1.8, U1.10
/ADC1/11: J1.5, U1.11
/ADC1/12: J1.6, U1.12
/ADC1/13: J1.3, U1.13
/ADC1/14: J1.4, U1.14
/ADC1/15: J1.1, U1.15
/ADC1/16: J1.2, U1.16
/ADC1/17: J2.15, U1.17
/ADC1/18: J2.16, U1.18
/ADC1/19: J2.13, U1.19
/ADC1/20: J2.14, U1.20
/ADC1/21: J2.11, U1.21
/ADC1/23: C7.2, C8.2, J2.9, U1.23
/ADC1/24: C5.2, C6.2, J2.10, U1.24
/ADC1/25: J2.7, U1.25
/ADC1/26: J2.8, U1.26
/ADC1/27: J2.5, U1.27
/ADC1/28: J2.6, U1.28
/ADC1/29: J2.3, U1.29
/ADC1/30: J2.4, U1.30
/ADC1/31: J2.1, U1.31
/ADC1/32: J2.2, U1.32
/ADC1/33: J3.15, U1.33
/ADC1/34: J3.16, U1.34
/ADC1/35: J3.13, U1.35
/ADC1/36: J3.14, U1.36
/ADC1/37: J3.11, U1.37
/ADC1/38: J3.12, U1.38
/ADC1/39: J3.9, U1.39
/ADC1/40: J3.10, U1.40
/ADC1/41: C9.2, C10.2, J3.7, U1.41
/ADC1/43: C11.2, C12.2, J3.5, U1.43
/ADC1/45: J3.3, U1.45
/ADC1/46: J3.4, U1.46
/ADC1/47: J3.1, U1.47
/ADC1/48: J3.2, U1.48
/ADC1/49: C13.1, J4.15, U1.49
/ADC1/51: C14.1, J4.13, U1.51
/ADC1/52: C15.2, C16.2, J4.14, U1.52
/ADC1/54: J4.12, U1.54
/ADC1/55: J4.9, U1.55
/ADC1/56: J4.10, U1.56
/ADC1/57: J4.7, U1.57
/ADC1/58: C17.2, C18.2, J4.8, U1.58
/ADC1/59: C19.1, J4.5, U1.59
/ADC1/62: C20.1, C21.1, J4.4, U1.62
/ADC1/63: J4.1, U1.63
/ADC1/64: J4.2, U1.64
/ADC2/1: J5.15, U2.1
/ADC2/2: J5.16, U2.2
/ADC2/3: J5.13, U2.3
/ADC2/4: J5.14, U2.4
/ADC2/6: C22.2, C23.2, J5.12, U2.6
/ADC2/8: C24.2, C25.2, J5.10, U2.8
/ADC2/9: J5.7, U2.9
/ADC2/10: J5.8, U2.10
/ADC2/11: J5.5, U2.11
/ADC2/12: J5.6, U2.12
/ADC2/13: J5.3, U2.13
/ADC2/14: J5.4, U2.14
/ADC2/15: J5.1, U2.15
/ADC2/16: J5.2, U2.16
/ADC2/17: J6.15, U2.17
/ADC2/18: J6.16, U2.18
/ADC2/19: J6.13, U2.19
/ADC2/20: J6.14, U2.20
/ADC2/21: J6.11, U2.21
/ADC2/23: C28.2, C29.2, J6.9, U2.23
/ADC2/24: C26.2, C27.2, J6.10, U2.24
/ADC2/25: J6.7, U2.25
/ADC2/26: J6.8, U2.26
/ADC2/27: J6.5, U2.27
/ADC2/28: J6.6, U2.28
/ADC2/29: J6.3, U2.29
/ADC2/30: J6.4, U2.30
/ADC2/31: J6.1, U2.31
/ADC2/32: J6.2, U2.32
/ADC2/33: J7.15, U2.33
/ADC2/34: J7.16, U2.34
/ADC2/35: J7.13, U2.35
/ADC2/36: J7.14, U2.36
/ADC2/37: J7.11, U2.37
/ADC2/38: J7.12, U2.38
/ADC2/39: J7.9, U2.39
/ADC2/40: J7.10, U2.40
/ADC2/41: C30.2, C31.2, J7.7, U2.41
/ADC2/43: C32.2, C33.2, J7.5, U2.43
/ADC2/45: J7.3, U2.45
/ADC2/46: J7.4, U2.46
/ADC2/47: J7.1, U2.47
/ADC2/48: J7.2, U2.48
/ADC2/49: C34.1, J8.15, U2.49
/ADC2/51: C35.1, J8.13, U2.51
/ADC2/52: C36.2, C37.2, J8.14, U2.52
/ADC2/54: J8.12, U2.54
/ADC2/55: J8.9, U2.55
/ADC2/56: J8.10, U2.56
/ADC2/57: J8.7, U2.57
/ADC2/58: C38.2, C39.2, J8.8, U2.58
/ADC2/59: C40.1, J8.5, U2.59
/ADC2/62: C41.1, C42.1, J8.4, U2.62
/ADC2/63: J8.1, U2.63
/ADC2/64: J8.2, U2.64
/ADC3/1: J9.15, U3.1
/ADC3/2: J9.16, U3.2
/ADC3/3: J9.13, U3.3
/ADC3/4: J9.14, U3.4
/ADC3/6: C43.2, C44.2, J9.12, U3.6
/ADC3/8: C45.2, C46.2, J9.10, U3.8
/ADC3/9: J9.7, U3.9
/ADC3/10: J9.8, U3.10
/ADC3/11: J9.5, U3.11
/ADC3/12: J9.6, U3.12
/ADC3/13: J9.3, U3.13
/ADC3/14: J9.4, U3.14
/ADC3/15: J9.1, U3.15
/ADC3/16: J9.2, U3.16
/ADC3/17: J10.15, U3.17
/ADC3/18: J10.16, U3.18
/ADC3/19: J10.13, U3.19
/ADC3/20: J10.14, U3.20
/ADC3/21: J10.11, U3.21
/ADC3/23: C49.2, C50.2, J10.9, U3.23
/ADC3/24: C47.2, C48.2, J10.10, U3.24
/ADC3/25: J10.7, U3.25
/ADC3/26: J10.8, U3.26
/ADC3/27: J10.5, U3.27
/ADC3/28: J10.6, U3.28
/ADC3/29: J10.3, U3.29
/ADC3/30: J10.4, U3.30
/ADC3/31: J10.1, U3.31
/ADC3/32: J10.2, U3.32
/ADC3/33: J11.15, U3.33
/ADC3/34: J11.16, U3.34
/ADC3/35: J11.13, U3.35
/ADC3/36: J11.14, U3.36
/ADC3/37: J11.11, U3.37
/ADC3/38: J11.12, U3.38
/ADC3/39: J11.9, U3.39
/ADC3/40: J11.10, U3.40
/ADC3/41: C51.2, C52.2, J11.7, U3.41
/ADC3/43: C53.2, C54.2, J11.5, U3.43
/ADC3/45: J11.3, U3.45
/ADC3/46: J11.4, U3.46
/ADC3/47: J11.1, U3.47
/ADC3/48: J11.2, U3.48
/ADC3/49: C55.1, J12.15, U3.49
/ADC3/51: C56.1, J12.13, U3.51
/ADC3/52: C57.2, C58.2, J12.14, U3.52
/ADC3/54: J12.12, U3.54
/ADC3/55: J12.9, U3.55
/ADC3/56: J12.10, U3.56
/ADC3/57: J12.7, U3.57
/ADC3/58: C59.2, C60.2, J12.8, U3.58
/ADC3/59: C61.1, J12.5, U3.59
/ADC3/62: C62.1, C63.1, J12.4, U3.62
/ADC3/63: J12.1, U3.63
/ADC3/64: J12.2, U3.64
/ADC4/1: J13.15, U4.1
/ADC4/2: J13.16, U4.2
/ADC4/3: J13.13, U4.3
/ADC4/4: J13.14, U4.4
/ADC4/6: C64.2, C65.2, J13.12, U4.6
/ADC4/8: C66.2, C67.2, J13.10, U4.8
/ADC4/9: J13.7, U4.9
/ADC4/10: J13.8, U4.10
/ADC4/11: J13.5, U4.11
/ADC4/12: J13.6, U4.12
/ADC4/13: J13.3, U4.13
/ADC4/14: J13.4, U4.14
/ADC4/15: J13.1, U4.15
/ADC4/16: J13.2, U4.16
/ADC4/17: J14.15, U4.17
/ADC4/18: J14.16, U4.18
/ADC4/19: J14.13, U4.19
/ADC4/20: J14.14, U4.20
/ADC4/21: J14.11, U4.21
/ADC4/23: C70.2, C71.2, J14.9, U4.23
/ADC4/24: C68.2, C69.2, J14.10, U4.24
/ADC4/25: J14.7, U4.25
/ADC4/26: J14.8, U4.26
/ADC4/27: J14.5, U4.27
/ADC4/28: J14.6, U4.28
/ADC4/29: J14.3, U4.29
/ADC4/30: J14.4, U4.30
/ADC4/31: J14.1, U4.31
/ADC4/32: J14.2, U4.32
/ADC4/33: J15.15, U4.33
/ADC4/34: J15.16, U4.34
/ADC4/35: J15.13, U4.35
/ADC4/36: J15.14, U4.36
/ADC4/37: J15.11, U4.37
/ADC4/38: J15.12, U4.38
/ADC4/39: J15.9, U4.39
/ADC4/40: J15.10, U4.40
/ADC4/41: C72.2, C73.2, J15.7, U4.41
/ADC4/43: C74.2, C75.2, J15.5, U4.43
/ADC4/45: J15.3, U4.45
/ADC4/46: J15.4, U4.46
/ADC4/47: J15.1, U4.47
/ADC4/48: J15.2, U4.48
/ADC4/49: C76.1, J16.15, U4.49
/ADC4/51: C77.1, J16.13, U4.51
/ADC4/52: C78.2, C79.2, J16.14, U4.52
/ADC4/54: J16.12, U4.54
/ADC4/55: J16.9, U4.55
/ADC4/56: J16.10, U4.56
/ADC4/57: J16.7, U4.57
/ADC4/58: C80.2, C81.2, J16.8, U4.58
/ADC4/59: C82.1, J16.5, U4.59
/ADC4/62: C83.1, C84.1, J16.4, U4.62
/ADC4/63: J16.1, U4.63
/ADC4/64: J16.2, U4.64
/AVDD/1: C109.1, J29.3, U10.1
/AVDD/2: C109.2, C110.2, J29.2, U10.2
/AVDD/3: J29.1, U10.3
/AVDD/4: J30.3, U10.4
/AVDD/5: C110.1, J30.1, U10.5
/CRYSTAL/1: J24.1, J24#2.1, U8.1, U8#2.1
/CRYSTAL/2: J24.2, J24#2.2, U8.2, U8#2.2
/CRYSTAL/3: J23.1, J23#2.1, U8.3, U8#2.3
/CRYSTAL/4: J23.2, J23#2.2, U8.4, U8#2.4
/IOVDD/1: C87.1, J19.3, U6.1
/IOVDD/2: C87.2, C88.2, J19.2, U6.2
/IOVDD/3: J19.1, U6.3
/IOVDD/4: J20.3, U6.4
/IOVDD/5: C88.1, J20.1, U6.5
/ISO1/1: C116.1, J39.1, U14.1
/ISO1/2: C116.2, J39.2, U14.2
/ISO1/3: J39.3, U14.3
/ISO1/4: J39.4, U14.4
/ISO1/5: J39.5, U14.5
/ISO1/6: J39.6, U14.6
/ISO1/7: J39.7, U14.7
/ISO1/8: J39.8, U14.8
/ISO1/9: J40.2, U14.9
/ISO1/10: J40.1, U14.10
/ISO1/11: J40.4, U14.11
/ISO1/12: J40.3, U14.12
/ISO1/13: J40.6, U14.13
/ISO1/14: J40.5, U14.14
/ISO1/15: C117.2, J40.8, U14.15
/ISO1/16: C117.1, J40.7, U14.16
/ISO2/1: C118.1, J41.1, U15.1
/ISO2/2: C118.2, J41.2, U15.2
/ISO2/3: J41.3, U15.3
/ISO2/4: J41.4, U15.4
/ISO2/5: J41.5, U15.5
/ISO2/6: J41.6, U15.6
/ISO2/7: J41.7, U15.7
/ISO2/8: J41.8, U15.8
/ISO2/9: J42.2, U15.9
/ISO2/10: J42.1, U15.10
/ISO2/11: J42.4, U15.11
/ISO2/12: J42.3, U15.12
/ISO2/13: J42.6, U15.13
/ISO2/14: J42.5, U15.14
/ISO2/15: C119.2, J42.8, U15.15
/ISO2/16: C119.1, J42.7, U15.16
/ISO3/1: C120.1, J43.1, U16.1
/ISO3/2: C120.2, J43.2, U16.2
/ISO3/3: J43.3, U16.3
/ISO3/4: J43.4, U16.4
/ISO3/5: J43.5, U16.5
/ISO3/6: J43.6, U16.6
/ISO3/7: J43.7, U16.7
/ISO3/8: J43.8, U16.8
/ISO3/9: J44.2, U16.9
/ISO3/10: J44.1, U16.10
/ISO3/11: J44.4, U16.11
/ISO3/12: J44.3, U16.12
/ISO3/13: J44.6, U16.13
/ISO3/14: J44.5, U16.14
/ISO3/15: C121.2, J44.8, U16.15
/ISO3/16: C121.1, J44.7, U16.16
/MCU/1: J25.35, U9.1
/MCU/2: J25.36, U9.2
/MCU/3: J25.33, U9.3
/MCU/4: J25.34, U9.4
/MCU/5: J25.31, U9.5
/MCU/6: J25.32, U9.6
/MCU/7: J25.29, U9.7
/MCU/8: J25.30, U9.8
/MCU/9: J25.27, U9.9
/MCU/10: J25.28, U9.10
/MCU/11: J25.25, U9.11
/MCU/12: J25.26, U9.12
/MCU/13: J25.23, U9.13
/MCU/14: J25.24, U9.14
/MCU/15: J25.21, U9.15
/MCU/17: C93.1, J25.19, U9.17
/MCU/18: J25.20, U9.18
/MCU/19: J25.17, U9.19
/MCU/20: J25.18, U9.20
/MCU/21: J25.15, U9.21
/MCU/22: J25.16, U9.22
/MCU/23: J25.13, U9.23
/MCU/24: J25.14, U9.24
/MCU/25: J25.11, U9.25
/MCU/26: J25.12, U9.26
/MCU/27: J25.9, U9.27
/MCU/28: J25.10, U9.28
/MCU/29: J25.7, U9.29
/MCU/30: C94.1, J25.8, U9.30
/MCU/32: C95.1, J25.6, U9.32
/MCU/33: C96.1, J25.3, U9.33
/MCU/34: J25.4, U9.34
/MCU/35: J25.1, U9.35
/MCU/36: J25.2, U9.36
/MCU/37: J26.35, U9.37
/MCU/39: C97.1, J26.33, U9.39
/MCU/40: J26.34, U9.40
/MCU/41: J26.31, U9.41
/MCU/42: J26.32, U9.42
/MCU/43: J26.29, U9.43
/MCU/44: J26.30, U9.44
/MCU/45: J26.27, U9.45
/MCU/46: J26.28, U9.46
/MCU/47: J26.25, U9.47
/MCU/48: J26.26, U9.48
/MCU/49: J26.23, U9.49
/MCU/50: J26.24, U9.50
/MCU/52: C98.1, C122.1, J26.22, U9.52
/MCU/53: J26.19, U9.53
/MCU/54: J26.20, U9.54
/MCU/55: J26.17, U9.55
/MCU/56: J26.18, U9.56
/MCU/57: J26.15, U9.57
/MCU/58: J26.16, U9.58
/MCU/59: J26.13, U9.59
/MCU/60: J26.14, U9.60
/MCU/62: C99.1, J26.12, U9.62
/MCU/63: J26.9, U9.63
/MCU/64: J26.10, U9.64
/MCU/65: J26.7, U9.65
/MCU/66: J26.8, U9.66
/MCU/67: J26.5, U9.67
/MCU/68: J26.6, U9.68
/MCU/69: J26.3, U9.69
/MCU/70: J26.4, U9.70
/MCU/71: C100.1, J26.1, U9.71
/MCU/72: C101.1, J26.2, U9.72
/MCU/73: J27.35, U9.73
/MCU/74: J27.36, U9.74
/MCU/75: J27.33, U9.75
/MCU/76: J27.34, U9.76
/MCU/77: J27.31, U9.77
/MCU/78: J27.32, U9.78
/MCU/79: J27.29, U9.79
/MCU/80: J27.30, U9.80
/MCU/81: J27.27, U9.81
/MCU/82: J27.28, U9.82
/MCU/84: C102.1, J27.26, U9.84
/MCU/85: J27.23, U9.85
/MCU/86: J27.24, U9.86
/MCU/87: J27.21, U9.87
/MCU/88: J27.22, U9.88
/MCU/89: J27.19, U9.89
/MCU/90: J27.20, U9.90
/MCU/91: J27.17, U9.91
/MCU/92: J27.18, U9.92
/MCU/93: J27.15, U9.93
/MCU/95: C103.1, J27.13, U9.95
/MCU/96: J27.14, U9.96
/MCU/97: J27.11, U9.97
/MCU/98: J27.12, U9.98
/MCU/99: J27.9, U9.99
/MCU/100: J27.10, U9.100
/MCU/101: J27.7, U9.101
/MCU/102: J27.8, U9.102
/MCU/103: J27.5, U9.103
/MCU/104: J27.6, U9.104
/MCU/105: J27.3, U9.105
/MCU/106: C104.1, J27.4, U9.106
/MCU/108: C105.1, J27.2, U9.108
/MCU/109: J28.35, U9.109
/MCU/110: J28.36, U9.110
/MCU/111: J28.33, U9.111
/MCU/112: J28.34, U9.112
/MCU/113: J28.31, U9.113
/MCU/114: J28.32, U9.114
/MCU/115: J28.29, U9.115
/MCU/116: J28.30, U9.116
/MCU/117: J28.27, U9.117
/MCU/118: J28.28, U9.118
/MCU/119: J28.25, U9.119
/MCU/121: C106.1, J28.23, U9.121
/MCU/122: J28.24, U9.122
/MCU/123: J28.21, U9.123
/MCU/124: J28.22, U9.124
/MCU/125: J28.19, U9.125
/MCU/126: J28.20, U9.126
/MCU/127: J28.17, U9.127
/MCU/128: J28.18, U9.128
/MCU/129: J28.15, U9.129
/MCU/131: C107.1, J28.13, U9.131
/MCU/132: J28.14, U9.132
/MCU/133: J28.11, U9.133
/MCU/134: J28.12, U9.134
/MCU/135: J28.9, U9.135
/MCU/136: J28.10, U9.136
/MCU/137: J28.7, U9.137
/MCU/138: J28.8, U9.138
/MCU/139: J28.5, U9.139
/MCU/140: J28.6, U9.140
/MCU/141: J28.3, U9.141
/MCU/142: J28.4, U9.142
/MCU/143: J28.1, U9.143
/MCU/144: C108.1, J28.2, U9.144
/POWER/1: C113.1, J35.1, U12.4
/POWER/2: C113.2, J35.2, T1.2, T1.3, U12.2, U12.5
/POWER/3: C114.1, C115.1, D1.1, D2.1, J36.1
/POWER/4: C114.2, C115.2, J36.2, T1.6, T1.7
/REF/1: J21.4, U7.1
/REF/2: C89.1, C90.1, J21.3, U7.2
/REF/3: J21.2, U7.3
/REF/4: C89.2, C90.2, C91.2, C92.2, J21.1, U7.4
/REF/5: J22.4, U7.5
/REF/6: C91.1, C92.1, J22.3, U7.6
/REF/7: J22.2, U7.7
/REF/8: J22.1, U7.8
/SD/1: J37.1, J37#2.1, U13.1, U13#2.1
/SD/2: J37.2, J37#2.2, U13.2, U13#2.2
/SD/3: J37.3, J37#2.3, U13.3, U13#2.3
/SD/4: J37.4, J37#2.4, U13.4, U13#2.4
/SD/5: J37.5, J37#2.5, U13.5, U13#2.5
/SD/6: J38.2, J38#2.2, U13.6, U13#2.6
/SD/7: J38.3, J38#2.3, U13.7, U13#2.7
/SD/8: J38.4, J38#2.4, U13.8, U13#2.8
/SD/9: J38.1, J38#2.1, U13.9, U13#2.9
/VDD/1: C85.1, J17.3, U5.1
/VDD/2: C85.2, C86.2, J17.2, U5.2
/VDD/3: J17.1, U5.3
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

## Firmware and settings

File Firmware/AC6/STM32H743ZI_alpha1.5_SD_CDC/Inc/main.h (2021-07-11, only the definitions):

#define ADC2_DRDY_Pin GPIO_PIN_13
#define ADC2_DRDY_GPIO_Port GPIOC
#define ADC2_START_Pin GPIO_PIN_4
#define ADC2_START_GPIO_Port GPIOF
#define ADC2_RESET_Pin GPIO_PIN_5
#define ADC2_RESET_GPIO_Port GPIOF
#define ISO_USB_PIN_Pin GPIO_PIN_7
#define ISO_USB_PIN_GPIO_Port GPIOF
#define ADC3_DRDY_Pin GPIO_PIN_10
#define ADC3_DRDY_GPIO_Port GPIOF
#define SPI1_NSS_Pin GPIO_PIN_4
#define SPI1_NSS_GPIO_Port GPIOA
#define ADC3_START_Pin GPIO_PIN_5
#define ADC3_START_GPIO_Port GPIOC
#define ADC1_DRDY_Pin GPIO_PIN_0
#define ADC1_DRDY_GPIO_Port GPIOB
#define ADC1_DRDY_EXTI_IRQn EXTI0_IRQn
#define ADC3_RESET_Pin GPIO_PIN_1
#define ADC3_RESET_GPIO_Port GPIOB
#define BOOT1_Pin GPIO_PIN_2
#define BOOT1_GPIO_Port GPIOB
#define SPI2_NSS_Pin GPIO_PIN_12
#define SPI2_NSS_GPIO_Port GPIOB
#define ADC4_START_Pin GPIO_PIN_2
#define ADC4_START_GPIO_Port GPIOG
#define ADC4_RESET_Pin GPIO_PIN_3
#define ADC4_RESET_GPIO_Port GPIOG
#define ADC4_DRDY_Pin GPIO_PIN_4
#define ADC4_DRDY_GPIO_Port GPIOG
#define SDMMC1_DETECT_Pin GPIO_PIN_7
#define SDMMC1_DETECT_GPIO_Port GPIOC
#define ADC1_START_Pin GPIO_PIN_4
#define ADC1_START_GPIO_Port GPIOD
#define ADC1_RESET_Pin GPIO_PIN_5
#define ADC1_RESET_GPIO_Port GPIOD
#define ACC_INT1_Pin GPIO_PIN_8
#define ACC_INT1_GPIO_Port GPIOB
#define ACC_SDO_SAO_Pin GPIO_PIN_9
#define ACC_SDO_SAO_GPIO_Port GPIOB
#define ACC_INT2_Pin GPIO_PIN_1
#define ACC_INT2_GPIO_Port GPIOE
#define AD_DRDY_Pin ADC1_DRDY_Pin
#define AD_DRDY_GPIO_Port ADC1_DRDY_GPIO_Port
#define SPI1_NSS_Pin GPIO_PIN_4
#define SPI1_NSS_GPIO_Port GPIOA
#define DHCP_SOCKET     0
#define DNS_SOCKET      1
#define HTTP_SOCKET     2
#define W5500_CS_GPIO_Port SPI1_NSS_GPIO_Port
#define W5500_CS_Pin SPI1_NSS_Pin
#define SPI2_NSS_Pin GPIO_PIN_12
#define SPI2_NSS_GPIO_Port GPIOB
#define SPI3_NSS_Pin GPIO_PIN_10
#define SPI3_NSS_GPIO_Port GPIOA
#define SPI4_NSS_Pin GPIO_PIN_8
#define SPI4_NSS_GPIO_Port GPIOG
#define SPI6_NSS_Pin GPIO_PIN_11
#define SPI6_NSS_GPIO_Port GPIOE
#define FREESMARTEEG_OPENBCI                   (1LL<<0)
#define FREESMARTEEG_PROCESSING                (1LL<<1)
#define FREESMARTEEG_CRC                       (1LL<<2)
#define FREESMARTEEG_TEXT                      (1LL<<3)
#define FREESMARTEEG_SAMPLECOUNT               (1LL<<4)
#define FREESMARTEEG_BLINK                     (1LL<<5)
#define FREESMARTEEG_FFT                       (1LL<<6)
#define FREESMARTEEG_DIF                       (1LL<<7)
#define FREESMARTEEG_TEST_COUNTER              (1LL<<8)
#define FREESMARTEEG_TEXT_UART1                (1LL<<9)
#define FREESMARTEEG_OPENVIBE_TELNET           (1LL<<10)
#define FREESMARTEEG_ARDUINO_MEGA_DISPLAY      (1LL<<11)
#define FREESMARTEEG_OPENVIBE_TELNET_PACKET    (1LL<<12)
#define FREESMARTEEG_OPENBCI_TELNET_PACKET     (1LL<<13)
#define FREESMARTEEG_OPENVIBE_FREEEEG32        (1LL<<14)
#define FREESMARTEEG_CHANNELS_STATE            (1LL<<15)
#define FREESMARTEEG_FFT_DISPLAY               (1LL<<16)
#define FREESMARTEEG_TEST_BLINK                (1LL<<17)
#define FREESMARTEEG_STABLE_CRC                (1LL<<18)
#define FREESMARTEEG_TEST_COUNTER2             (1LL<<19)
#define FREESMARTEEG_TEST_BLINK2               (1LL<<20)
#define FREESMARTEEG_DEVICES_STATE             (1LL<<21)
#define FREESMARTEEG_TEXT_USB                  (1LL<<22)
#define FREESMARTEEG_TEXT_SDCARD               (1LL<<23)
#define FREESMARTEEG_SDCARD_TEXT               (1LL<<24)
#define FREESMARTEEG_TEST_SDCARD               (1LL<<25)
#define FREESMARTEEG_WRITE_SDCARD              (1LL<<26)
#define FREESMARTEEG_SDCARD_OPENVIBE           (1LL<<27)
#define FREESMARTEEG_WRITE_SDCARD_OPENVIBE     (1LL<<28)
#define FREESMARTEEG_SDCARD_FORMAT             (1LL<<29)
#define FREESMARTEEG_TEXT_UART7                (1LL<<30)
#define FREESMARTEEG_DATA_TEXT_UART7           (1LL<<31)
#define FREESMARTEEG_DATA_OPENVIBE_FREEEEG32   (1LL<<32)
#define FREESMARTEEG_TEST_ACCGYR_SPI3          (1LL<<33)
#define FREESMARTEEG_OPENVIBE_FREEEEG32_CUSTOM (1LL<<34)
#define FREESMARTEEG_DATA_OPENVIBE_FREEEEG32_CUSTOM (1LL<<35)
#define FREESMARTEEG_DATA_TEXT_UART7_INT       (1LL<<36)
#define FREESMARTEEG_DATA_OPENVIBE_FREEEEG32_CUSTOM_INT (1LL<<37)
#define FREESMARTEEG_SPI_OPENVIBE_FREEEEG32_CUSTOM_INT (1LL<<38)
#define FREESMARTEEG_TEXT_UART7_SAI2B_TIMER     (1LL<<40)
#define FREESMARTEEG_OPENVIBE_FREEEEG32_UART7_SAI2B_TIMER     (1LL<<41)
#define FREESMARTEEG_DMA_UART7_SAI2B_TIMER     (1LL<<42)
#define FREESMARTEEG_SAI_TEXT_UART7_INT       (1LL<<43)
#define FREESMARTEEG_SAI_OPENVIBE_FREEEEG32_CUSTOM_INT (1LL<<44)
#define FREESMARTEEG_SAI_TEXT_UART7     (1LL<<45)
#define FREESMARTEEG_SAI_OPENVIBE_FREEEEG32_CUSTOM (1LL<<46)
#define FREESMARTEEG_I2S_TEXT_UART7_INT     (1LL<<47)
#define FREESMARTEEG_I2S_OPENVIBE_FREEEEG32_CUSTOM_INT (1LL<<48)
#define FREESMARTEEG_I2S_TEXT_UART7     (1LL<<49)
#define FREESMARTEEG_I2S_OPENVIBE_FREEEEG32_CUSTOM (1LL<<50)
#define FREESMARTEEG_SPI_TEXT_UART7_INT (1LL<<51)
#define FREESMARTEEG_SAI_TEXT_UART7_INT_DMA       (1LL<<52)
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

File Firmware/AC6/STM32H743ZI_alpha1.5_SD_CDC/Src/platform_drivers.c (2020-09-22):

/***************************************************************************//**
* @file platform_drivers.c
* @brief Implementation of Platform Drivers.
* @author DBogdan (dragos.bogdan@analog.com)
********************************************************************************
* Copyright 2014-2015(c) Analog Devices, Inc.
*
* All rights reserved.
*
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
* THIS SOFTWARE IS PROVIDED BY ANALOG DEVICES "AS IS" AND ANY EXPRESS OR
* IMPLIED WARRANTIES, INCLUDING, BUT NOT LIMITED TO, NON-INFRINGEMENT,
* MERCHANTABILITY AND FITNESS FOR A PARTICULAR PURPOSE ARE DISCLAIMED.
* IN NO EVENT SHALL ANALOG DEVICES BE LIABLE FOR ANY DIRECT, INDIRECT,
* INCIDENTAL, SPECIAL, EXEMPLARY, OR CONSEQUENTIAL DAMAGES (INCLUDING, BUT NOT
* LIMITED TO, INTELLECTUAL PROPERTY RIGHTS, PROCUREMENT OF SUBSTITUTE GOODS OR
* SERVICES; LOSS OF USE, DATA, OR PROFITS; OR BUSINESS INTERRUPTION) HOWEVER
* CAUSED AND ON ANY THEORY OF LIABILITY, WHETHER IN CONTRACT, STRICT LIABILITY,
* OR TORT (INCLUDING NEGLIGENCE OR OTHERWISE) ARISING IN ANY WAY OUT OF THE USE
* OF THIS SOFTWARE, EVEN IF ADVISED OF THE POSSIBILITY OF SUCH DAMAGE.
*******************************************************************************/

/******************************************************************************/
/***************************** Include Files **********************************/
/******************************************************************************/

#include "stm32h7xx_hal.h"

#include "main.h"
#include "platform_drivers.h"

/******************************************************************************/
/************************ Variables Definitions *******************************/
/******************************************************************************/


#ifdef _XPARAMETERS_PS_H_
XSpiPs_Config	*spi_config;
XSpiPs			spi_instance;
XGpioPs_Config	*gpio_config;
XGpioPs			gpio_instance;
uint8_t			spi_decoded_cs = 0;
#else
//XSpi_Config		*spi_config;
//XSpi			spi_instance;
//XGpio_Config	*gpio_config;
//XGpio			gpio_instance;

//SPI_HandleTypeDef* hhspi1;
//UART_HandleTypeDef* huart;

#endif

/***************************************************************************//**
* @brief spi_init
*******************************************************************************/
int32_t spi_init(SPI_HandleTypeDef* hspi/*uint32_t device_id,
				 uint8_t clk_pha,
				 uint8_t clk_pol*/)
{
	uint32_t base_addr	 = 0;
	uint32_t spi_options = 0;

#ifdef _XPARAMETERS_PS_H_
	spi_config = XSpiPs_LookupConfig(device_id);

	base_addr = spi_config->BaseAddress;
	XSpiPs_CfgInitialize(&spi_instance, spi_config, base_addr);

	spi_options = XSPIPS_MASTER_OPTION |
			(clk_pol ? XSPIPS_CLK_ACTIVE_LOW_OPTION : 0) |
			(clk_pha ? XSPIPS_CLK_PHASE_1_OPTION : 0) |
			(spi_decoded_cs ? XSPIPS_DECODE_SSELECT_OPTION : 0) |
			XSPIPS_FORCE_SSELECT_OPTION;
	XSpiPs_SetOptions(&spi_instance, spi_options);

	XSpiPs_SetClkPrescaler(&spi_instance, XSPIPS_CLK_PRESCALE_32);

	/* FIXME: Temporary 15.2 Fix */
	XSpiPs_CfgInitialize(&spi_instance, spi_config, base_addr);

	XSpiPs_SetOptions(&spi_instance, spi_options);

	XSpiPs_SetClkPrescaler(&spi_instance, XSPIPS_CLK_PRESCALE_32);
#else
//	hhspi1 = hspi;
/*
  hspi1.Instance = SPI1;
  hspi1.Init.Mode = SPI_MODE_MASTER;
  hspi1.Init.Direction = SPI_DIRECTION_2LINES;
  hspi1.Init.DataSize = SPI_DATASIZE_8BIT;
  hspi1.Init.CLKPolarity = SPI_POLARITY_LOW;
  hspi1.Init.CLKPhase = SPI_PHASE_1EDGE;
  hspi1.Init.NSS = SPI_NSS_HARD_OUTPUT;
//  hspi1.Init.NSS = SPI_NSS_SOFT;
  hspi1.Init.BaudRatePrescaler = SPI_BAUDRATEPRESCALER_8;
  hspi1.Init.FirstBit = SPI_FIRSTBIT_MSB;
  hspi1.Init.TIMode = SPI_TIMODE_DISABLED;
  hspi1.Init.CRCCalculation = SPI_CRCCALCULATION_DISABLED;

	HAL_SPI_Init(hspi1);*/
//  HAL_SPI_MspInit(hspi);

/*	XSpi_Initialize(&spi_instance, device_id);

	XSpi_Stop(&spi_instance);

	spi_config = XSpi_LookupConfig(device_id);

	base_addr = spi_config->BaseAddress;
	XSpi_CfgInitialize(&spi_instance, spi_config, base_addr);

	spi_options = XSP_MASTER_OPTION |
				  (clk_pol ? XSP_CLK_ACTIVE_LOW_OPTION : 0) |
				  (clk_pha ? XSP_CLK_PHASE_1_OPTION : 0) |
				  XSP_MANUAL_SSELECT_OPTION;
	XSpi_SetOptions(&spi_instance, spi_options);

	XSpi_Start(&spi_instance);

	XSpi_IntrGlobalDisable(&spi_instance);*/
/*
	GPIO_InitTypeDef port;
	SPI_InitTypeDef spi;

  //Тут абсолютно вся инициализация
  RCC_APB2PeriphClockCmd(RCC_APB2Periph_GPIOA, ENABLE);
//  RCC_APB2PeriphClockCmd(RCC_APB2Periph_GPIOB, ENABLE);
  RCC_APB2PeriphClockCmd(RCC_APB2Periph_SPI1, ENABLE);
//  RCC_APB1PeriphClockCmd(RCC_APB1Periph_SPI2, ENABLE);
  RCC_APB2PeriphClockCmd(RCC_APB2Periph_AFIO, ENABLE);
*/

//  GPIO_PinRemapConfig(GPIO_Remap_SWJ_JTAGDisable, ENABLE); // Requires AFIO clock enabled, Map JTAG Off pins PB3,4,5, SWD still viable on PA13,14
//  GPIO_PinRemapConfig(GPIO_Remap_SPI1, ENABLE);

//  port.GPIO_Mode = GPIO_Mode_Out_PP;
//  port.GPIO_Pin = GPIO_Pin_12 | GPIO_Pin_13 | GPIO_Pin_14 | GPIO_Pin_15;
//  port.GPIO_Mode = GPIO_Mode_Out_PP;
/*  port.GPIO_Mode = GPIO_Mode_AF_PP;
port.GPIO_Pin = GPIO_Pin_3 | GPIO_Pin_5;
//  port.GPIO_Pin = GPIO_Pin_3 | GPIO_Pin_4 | GPIO_Pin_5;
port.GPIO_Speed = GPIO_Speed_50MHz;
GPIO_Init(GPIOB, &port);

port.GPIO_Mode = GPIO_Mode_IN_FLOATING;
port.GPIO_Pin = GPIO_Pin_4;
port.GPIO_Speed = GPIO_Speed_50MHz;
GPIO_Init(GPIOB, &port);

port.GPIO_Mode = GPIO_Mode_AF_PP;
port.GPIO_Pin = GPIO_Pin_15;
port.GPIO_Speed = GPIO_Speed_50MHz;
GPIO_Init(GPIOA, &port);

  SPI_I2S_DeInit(SPI1);

port.GPIO_Mode = GPIO_Mode_Out_PP;
port.GPIO_Pin = GPIO_Pin_4;
port.GPIO_Speed = GPIO_Speed_50MHz;
GPIO_Init(GPIOA, &port);*/

//  SPI_I2S_DeInit(SPI1);
/*
  port.GPIO_Mode = GPIO_Mode_AF_PP;
//  port.GPIO_Mode = GPIO_Mode_Out_PP;
  port.GPIO_Pin = GPIO_Pin_5 | GPIO_Pin_7;// | GPIO_Pin_6;
//  port.GPIO_Pin = GPIO_Pin_4 | GPIO_Pin_5 | GPIO_Pin_7 | = GPIO_Pin_6;
//  port.GPIO_Speed = GPIO_Speed_2MHz;
    port.GPIO_Speed = GPIO_Speed_50MHz;
  GPIO_Init(GPIOA, &port);

//  port.GPIO_Mode = GPIO_Mode_AF_PP;
  port.GPIO_Mode = GPIO_Mode_Out_PP;
  port.GPIO_Pin = GPIO_Pin_4;
//  port.GPIO_Speed = GPIO_Speed_2MHz;
    port.GPIO_Speed = GPIO_Speed_50MHz;
  GPIO_Init(GPIOA, &port);
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

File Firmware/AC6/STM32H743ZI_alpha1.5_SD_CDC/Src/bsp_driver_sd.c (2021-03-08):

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

/* USER CODE BEGIN FirstSection */
/* can be used to modify / undefine following code or add new definitions */
/* USER CODE END FirstSection */
/* Includes ------------------------------------------------------------------*/
#include "bsp_driver_sd.h"

/* Extern variables ---------------------------------------------------------*/

extern SD_HandleTypeDef hsd1;

/* USER CODE BEGIN BeforeInitSection */
/* can be used to modify / undefine following code or add code */
/* USER CODE END BeforeInitSection */
/**
  * @brief  Initializes the SD card device.
  * @retval SD status
  */
__weak uint8_t BSP_SD_Init(void)
{
  uint8_t sd_state = MSD_OK;
  /* Check if the SD card is plugged in the slot */
  if (BSP_SD_IsDetected() != SD_PRESENT)
  {
    return MSD_ERROR_SD_NOT_PRESENT;
  }
  /* HAL SD initialization */
  sd_state = HAL_SD_Init(&hsd1);
  /* Configure SD Bus width (4 bits mode selected) */
  if (sd_state == MSD_OK)
  {
    /* Enable wide operation */
    if (HAL_SD_ConfigWideBusOperation(&hsd1, SDMMC_BUS_WIDE_4B) != HAL_OK)
    {
      sd_state = MSD_ERROR;
    }
  }

  return sd_state;
}
/* USER CODE BEGIN AfterInitSection */
/* can be used to modify previous code / undefine following code / add code */
/* USER CODE END AfterInitSection */

/* USER CODE BEGIN InterruptMode */
/**
  * @brief  Configures Interrupt mode for SD detection pin.
  * @retval Returns 0
  */
__weak uint8_t BSP_SD_ITConfig(void)
{  
  /* Code to be updated by the user or replaced by one from the FW pack (in a stmxxxx_sd.c file) */
  
  return (uint8_t)0;
}

/* USER CODE END InterruptMode */

/* USER CODE BEGIN BeforeReadBlocksSection */
/* can be used to modify previous code / undefine following code / add code */
/* USER CODE END BeforeReadBlocksSection */
/**
  * @brief  Reads block(s) from a specified address in an SD card, in polling mode.
  * @param  pData: Pointer to the buffer that will contain the data to transmit
  * @param  ReadAddr: Address from where data is to be read
  * @param  NumOfBlocks: Number of SD blocks to read
  * @param  Timeout: Timeout for read operation
  * @retval SD status
  */
__weak uint8_t BSP_SD_ReadBlocks(uint32_t *pData, uint32_t ReadAddr, uint32_t NumOfBlocks, uint32_t Timeout)
{
  uint8_t sd_state = MSD_OK;

  if (HAL_SD_ReadBlocks(&hsd1, (uint8_t *)pData, ReadAddr, NumOfBlocks, Timeout) != HAL_OK)
  {
    sd_state = MSD_ERROR;
  }

  return sd_state;
}

/* USER CODE BEGIN BeforeWriteBlocksSection */
/* can be used to modify previous code / undefine following code / add code */
/* USER CODE END BeforeWriteBlocksSection */
/**
  * @brief  Writes block(s) to a specified address in an SD card, in polling mode.
  * @param  pData: Pointer to the buffer that will contain the data to transmit
  * @param  WriteAddr: Address from where data is to be written
  * @param  NumOfBlocks: Number of SD blocks to write
  * @param  Timeout: Timeout for write operation
  * @retval SD status
  */
__weak uint8_t BSP_SD_WriteBlocks(uint32_t *pData, uint32_t WriteAddr, uint32_t NumOfBlocks, uint32_t Timeout)
{
  uint8_t sd_state = MSD_OK;

  if (HAL_SD_WriteBlocks(&hsd1, (uint8_t *)pData, WriteAddr, NumOfBlocks, Timeout) != HAL_OK)
  {
    sd_state = MSD_ERROR;
  }

  return sd_state;
}

/* USER CODE BEGIN BeforeReadDMABlocksSection */
/* can be used to modify previous code / undefine following code / add code */
/* USER CODE END BeforeReadDMABlocksSection */
/**
  * @brief  Reads block(s) from a specified address in an SD card, in DMA mode.
  * @param  pData: Pointer to the buffer that will contain the data to transmit
  * @param  ReadAddr: Address from where data is to be read
  * @param  NumOfBlocks: Number of SD blocks to read
  * @retval SD status
  */
__weak uint8_t BSP_SD_ReadBlocks_DMA(uint32_t *pData, uint32_t ReadAddr, uint32_t NumOfBlocks)
{
  uint8_t sd_state = MSD_OK;

  /* Read block(s) in DMA transfer mode */
  if (HAL_SD_ReadBlocks_DMA(&hsd1, (uint8_t *)pData, ReadAddr, NumOfBlocks) != HAL_OK)
  {
    sd_state = MSD_ERROR;
  }

  return sd_state;
}

/* USER CODE BEGIN BeforeWriteDMABlocksSection */
/* can be used to modify previous code / undefine following code / add code */
/* USER CODE END BeforeWriteDMABlocksSection */
/**
  * @brief  Writes block(s) to a specified address in an SD card, in DMA mode.
  * @param  pData: Pointer to the buffer that will contain the data to transmit
  * @param  WriteAddr: Address from where data is to be written
  * @param  NumOfBlocks: Number of SD blocks to write
  * @retval SD status
  */
__weak uint8_t BSP_SD_WriteBlocks_DMA(uint32_t *pData, uint32_t WriteAddr, uint32_t NumOfBlocks)
{
  uint8_t sd_state = MSD_OK;

  /* Write block(s) in DMA transfer mode */
  if (HAL_SD_WriteBlocks_DMA(&hsd1, (uint8_t *)pData, WriteAddr, NumOfBlocks) != HAL_OK)
  {
    sd_state = MSD_ERROR;
  }

  return sd_state;
}

/* USER CODE BEGIN BeforeEraseSection */
/* can be used to modify previous code / undefine following code / add code */
/* USER CODE END BeforeEraseSection */
/**
  * @brief  Erases the specified memory area of the given SD card.
  * @param  StartAddr: Start byte address
  * @param  EndAddr: End byte address
  * @retval SD status
  */
__weak uint8_t BSP_SD_Erase(uint32_t StartAddr, uint32_t EndAddr)
{
  uint8_t sd_state = MSD_OK;

  if (HAL_SD_Erase(&hsd1, StartAddr, EndAddr) != HAL_OK)
  {
    sd_state = MSD_ERROR;
  }

  return sd_state;
}

/* USER CODE BEGIN BeforeGetCardStateSection */
/* can be used to modify previous code / undefine following code / add code */
/* USER CODE END BeforeGetCardStateSection */

/**
  * @brief  Gets the current SD card data status.
  * @param  None
  * @retval Data transfer state.
  *          This value can be one of the following values:
  *            @arg  SD_TRANSFER_OK: No data transfer is acting
  *            @arg  SD_TRANSFER_BUSY: Data transfer is acting
  */
__weak uint8_t BSP_SD_GetCardState(void)
{
  return ((HAL_SD_GetCardState(&hsd1) == HAL_SD_CARD_TRANSFER ) ? SD_TRANSFER_OK : SD_TRANSFER_BUSY);
}

/**
  * @brief  Get SD information about specific SD card.
  * @param  CardInfo: Pointer to HAL_SD_CardInfoTypedef structure
  * @retval None
  */
__weak void BSP_SD_GetCardInfo(HAL_SD_CardInfoTypeDef *CardInfo)
{
  /* Get SD card Information */
  HAL_SD_GetCardInfo(&hsd1, CardInfo);
}

/* USER CODE BEGIN BeforeCallBacksSection */
/* can be used to modify previous code / undefine following code / add code */
/* USER CODE END BeforeCallBacksSection */
/**
  * @brief SD Abort callbacks
  * @param hsd: SD handle
  * @retval None
  */
__weak void HAL_SD_AbortCallback(SD_HandleTypeDef *hsd)
{
  BSP_SD_AbortCallback();
}

/**
  * @brief Tx Transfer completed callback
  * @param hsd: SD handle
  * @retval None
  */
__weak void HAL_SD_TxCpltCallback(SD_HandleTypeDef *hsd)
{
  BSP_SD_WriteCpltCallback();
}

/**
  * @brief Rx Transfer completed callback
  * @param hsd: SD handle
  * @retval None
  */
__weak void HAL_SD_RxCpltCallback(SD_HandleTypeDef *hsd)
{
  BSP_SD_ReadCpltCallback();
}
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

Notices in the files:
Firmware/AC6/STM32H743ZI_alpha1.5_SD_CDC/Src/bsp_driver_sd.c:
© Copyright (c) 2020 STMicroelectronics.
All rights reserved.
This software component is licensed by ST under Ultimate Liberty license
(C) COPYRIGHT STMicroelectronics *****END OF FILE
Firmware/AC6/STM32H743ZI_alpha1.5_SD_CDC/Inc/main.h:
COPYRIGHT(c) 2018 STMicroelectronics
